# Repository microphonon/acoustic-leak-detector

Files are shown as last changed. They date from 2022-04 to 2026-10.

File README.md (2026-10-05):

# acoustic-leak-detector
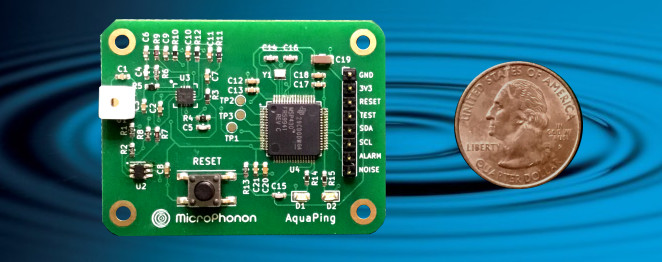
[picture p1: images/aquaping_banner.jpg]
MicroPhonon Acoustic Leak Detector


The best place to start is with the comprehensive user guide. An academic paper that describes the device design and performance can be found at [arXiv.org](https://arxiv.org/abs/2511.00348). 

 The AquaPing hardware with pre-loaded firmware is available for purchase at [Mouser](https://www.mouser.com/ProductDetail/MicroPhonon/CS-AQUAPING-01?qs=IPgv5n7u5QZ96LnbcZcGBA%3D%3D) or  [Crowd Supply](https://www.crowdsupply.com/microphonon/aquaping).

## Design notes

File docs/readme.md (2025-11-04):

# Documentation

In this repository:
- Acoustic leak detector design guide and I2C communication instructions (.pdf)
- Top-level firmware flow chart (.jpg)
- One-page engineering brochure (.pdf)
- Detecting simulated leaks inside a drywall structure (.pdf)

An academic paper describing the engineering design of the acoustic leak sensor is available for free download at [arXiv.org](https://arxiv.org/abs/2511.00348).

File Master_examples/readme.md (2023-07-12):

# Master firmware examples

Sample code to periodically read/write bytes from/to the AquaPing slave on the I2C bus. 
    Developed and tested with a Lolin D1 mini WiFi module as master, but should adapt to 
    other devices using the Arduino IDE and equivalent libraries. The D1 mini uses the Espressif ESP8266 for WiFi capability.
    
- **D1_mini.ino**  D1 mini transfers data between PC and sensor
-  **ThingSpeak.ino** D1 mini is used to: i) transfer data between PC and sensor and ii) upload data to ThingSpeak server over WiFi
    
 The D1 mini module provides a UART to USB interface to allow communication with a PC. 
    Any serial terminal program (eg. putty) should work; be sure to set equivalent baud rates. 
    The master can monitor the alarm state of the slave with a separate INTERRUPT_PIN (lowest latency) 
    as well as reading the first byte of the status_array. 
    
 Command characters are read from the serial terminal as user input. Characters are echoed to 
    the terminal then formatted into command strings as a sequence of hex bytes that are sent to slave. 
    Syntax is in separate documentation.

 The sensor status is polled at a period set by polling_interval in milliseconds. The retrieved 
    status bytes are then sent to the terminal. Each I2C read operation is signaled by the D1 mini LED blinking. 
    To allow the user to send sensor configuration commands with reasonably low latency, the terminal 
    is checked for input with a period set by sleep_delay. 
    
It is important to understand that the rate at which
    the master polls the slave (i.e. sensor) is not the same rate that the sensor polls the environment. These polling 
    loops run asynchronously. The slave MCU prevents I2C bus conflicts by moving data via Direct Memory Access, which requires no
    CPU intervention. 

The D1 mini can supply 3V3 external power to the sensor.
    Make sure a large electrolytic filter capacitor is on this line.
    The module already has pullup resistors for SDA and SCL.

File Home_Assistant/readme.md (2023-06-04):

# AquaPing demo with Home Assistant

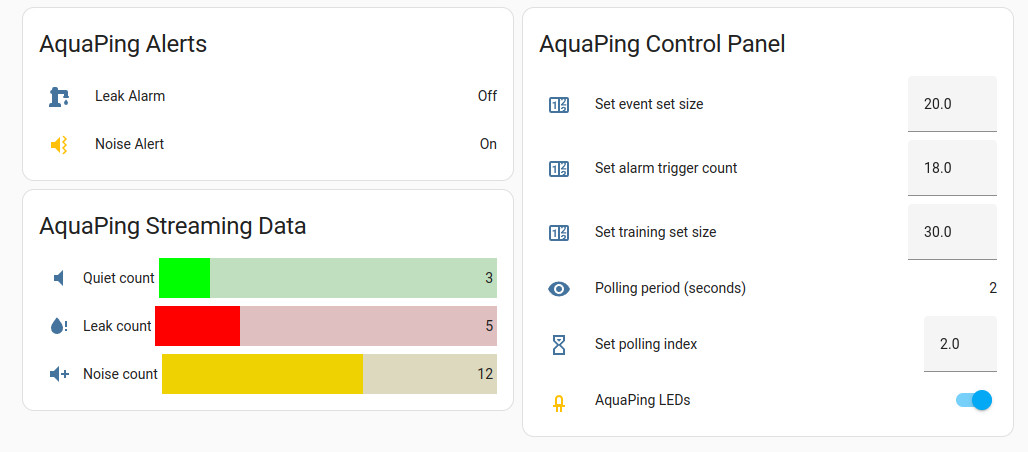
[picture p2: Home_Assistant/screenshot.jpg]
AquaPing Home Assistant Demo


This repository demonstrates how the [AquaPing](https://www.crowdsupply.com/microphonon/aquaping) acoustic leak detector can be interfaced to Home Assistant with [ESPHome](https://esphome.io/). It uses the ESP8266 WiFi module on an inexpensive [D1-mini](https://www.wemos.cc/en/latest/d1/d1_mini.html) breakout board. Although WiFi is not the preferred wireless protocol for ultralow power IoT applications, this Home Assistant application is useful for illustrating the sensor's principles of operation and its capabilities. Real-time data is displayed on a custom HA UI frontend that is also used to configure the sensor monitoring parameters.

The AquaPing is designed to listen for very weak, high frequency acoustics that may accompany a pressurized plumbing leak. The frontend screenshot shown above depicts sensor operation with music playing nearby. This is impairing the sensor's ability hear potential leak signals. An appreciable number of sample counts are being interpreted as noise causing the corresponding alert to trigger (On). Noise discrimination and rejection are important for preventing false leak alarms.

Development was done running the Home Assistant operating system inside VirtualBox on Ubuntu Linux. [ESPHome](https://esphome.io/) is installed as a native Home Assistant Add-on. The *aquaping.h* header file must be present in the config/esphome/ directory. It can be configured with the HA File Editor Add-on and is an *include* in the custom ESPHome yaml file that is found in this repository. The optional horizontal bar graphs require the [bar-card](https://github.com/custom-cards/bar-card) and [config-template-card](https://github.com/iantrich/config-template-card) modules that were installed using [Home Assistant Community Store](https://hacs.xyz/) (a github account is required). There are plenty of good online tutorials that can guide you through the various install processes.

## D1-mini hardware

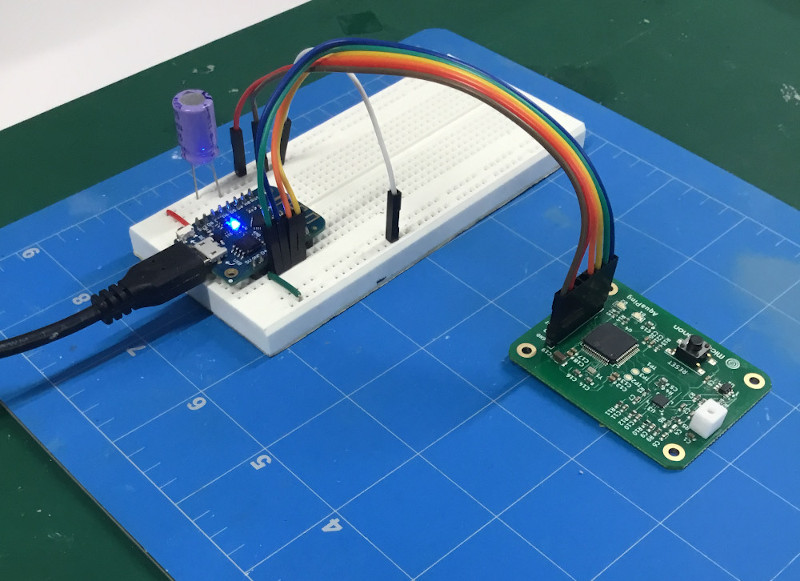
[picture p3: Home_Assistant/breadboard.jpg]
D1-mini hardware


The D1-mini is an inexpensive ESP8266 WiFi breakout board that is available from a variety of vendors. It communicates with the AquaPing using the I2C interface. SCL connects to pin D1 and SDA to pin D2 on the D1-mini. Pullup resistors are already present on the breakout board. The D1-mini can supply 3V3 DC power to the AquaPing *provided* the supply rail is sufficiently quiet. In the photo above, a 220 uF electrolytic decoupling capacitor is placed across 3V3 and ground on the breadboard. The NOISE and ALARM pins of the AquaPing are connected to D3 and D4, respectively. These lines provide an immediate GPIO interrupt if a suspected leak or persistent noise are detected. Other GPIO pins may be used if the configuration is appropriately modified.

Because the D1-mini operates as an always-on WiFi radio, its power consumption will be orders of magnitude greater than the AquaPing sensor. In this demo, power is supplied through the USB connection on the breakout board. If the USB connection is made to a host computer, a serial terminal program (eg. puTTY) can also be used to communicate with the AquaPing. Default baud rate is 9600; adjust as needed in the *aquaping.h* file. More information about the serial protocol can be found in the AquaPing user guide located in this repository.

Another option that could allow extended battery operation is to place the D1-mini in deep sleep, wake it up at periodic intervals, and let it re-connect to the WiFi router. The longer the period, the greater the battery life, but with increased sensor latency. This would require modifications to the D1-mini firmware.

## D1-mini firmware

C++ code to control operation of the D1-mini is in the header file *aquaping.h*. It uses the common Arduino abstractions and must be declared as an include in the yaml file. It is important to understand that this demo implements two independent, asynchronous polling loops running on the D1-mini and AquaPing:

1) **Polling the sensor.** Sensor information is downloaded to and uploaded from Home Assistant over WiFi with a period set by the 'update_interval' (ms) in the D1-mini firmware; default is 10000 ms, i.e. 10 seconds. 

2) **Periodic analysis of the environmental acoustics.** The AquaPing spends most of the time in a sleep state, but periodically wakes up to sample the acoustic environment. This interval is set by selecting one of 9 fixed periods with duration in the range 1--30 seconds; see the user manual. 

There are many examples of sensors uploading data via I2C and displaying it on the Home Assistant dashboard. Going in the other direction, however, is not well documented. This capability is needed to send configuration parameters to the AquaPing.  In this demo, frontend data is passed through the ESPHome yaml to the firmware where it is sent as byte pairs using the *Wire* library. The methodology used for I2C read/write operations is illustrated in [this document](i2c.md).

### Troubleshooting
When firmware is already loaded on the D1-mini, ESPHome may not be able to overwrite it. If the reset button is ineffective, try the following procedure: On the D1-mini, connect pin D3 to ground, pin D4 to 3.3V, and pin D8 to ground. Then try flashing the new firmware from ESPHome.

## Dashboard

The Home Assistant dashboard is highly configurable. Three dashboard cards are used here for alerts, streaming data, and control. Interrupts for potential leaks and anomalous noise are immediate and displayed on the alert card. The dashboard card with the data counts is updated only on each WiFi polling cycle, which introduces some latency. Similarly, adjustments to the AquaPing control panel are transmitted to the sensor at the same rate and latency. 

The alarm_trigger_count must be set to less than or equal to the event_set_size. If set higher, it will be coerced to the event_set_size. The control panel selects the polling period with an integer index (1--9) and the corresponding time is displayed in seconds. If the training_set_size is changed, a new training session will be automatically initiated. All configuration parameters are explained in the user guide. A switch is provided to enable/disable the AquaPing LEDs.

The horizontal bar graphs are optional, quite tricky to setup, and require installation of the [bar-card](https://github.com/custom-cards/bar-card) and [config-template-card](https://github.com/iantrich/config-template-card) modules. The latter is needed to re-scale the graph maxima when the user changes the event_set_size. See the included dashboard file for the syntax. There may be alternative techniques that could work better to render these graphics. Real-time counts can also be displayed using simpler numeric indicators. These can be added to the dashboard by editing the ESPHome yaml file.

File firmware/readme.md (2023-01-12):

# Modifying and compiling the code
The firmware was developed using Code Composer Studio 9.3.0 on an Ubuntu-Linux platform. CCS is a free download from Texas Instruments and provides an Eclipse style interface. The MSP430FR5994 MCU on the PCB is flashed using the Spy-Bi-Wire two-terminal interface marked RESET and TEST on the leak sensor PCB. Almost any variety of inexpensive TI Launchpads can be used for this purpose. The Launchpads have a debugger and an Energy Trace function that is useful for identifying code inefficiencies and estimating battery life. Alternatively, compiled binaries can be flashed with the MSP430-BSL made by Olimex and available at [Mouser](https://www.mouser.com/ProductDetail/Olimex-Ltd/MSP430-BSL?qs=J7x7253A5u5ktaUHQ83VeQ%3D%3D).

A capability for over-the-air firmware updates is an anticipated future upgrade. This can be accomplished using the I2C terminals SDA and SCL in addition to the RESET and TEST pins. The required MCU part number is MSP430FR59941 as distinguished from MSP430FR5994 that uses a UART connection with the master. A UART design must include TXD and RXD pins, increasing the header pin count from 7 to 9. If OTA upgrades are not necessary, either variety of MCU will work.

The Texas Instruments [MSP DSP Library](https://software-dl.ti.com/msp430/msp430_public_sw/mcu/msp430/DSPLib/1_30_00_02/exports/html/index.html) must be installed on the development platform, also a free download.  Use your file explorer to copy the dsplib directory directly into the CCS project folder. Enable DSP by navigating to:

 CCS Build: MSP430 Compiler: Include Options

and adding the following line:

 ${PROJECT_ROOT}/dsplib/include
 
The 48-pin version was used for the prototypes and is archived here. For the production run in late 2022, only the 64-pin MSP430FR59941 MCU was available; ongoing firmware development and updates are being done for this hardware. As of December 2022, the 64-pin sensor is being sold by Crowd Supply and Mouser. The firmware version can be read from the status array (see user manual).

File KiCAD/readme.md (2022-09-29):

# KiCAD files
There are two versions of the PCB for designs using either a 48- or 64-pin MSP430FR5994 microcontroller. Both the schematic and layout KiCAD files use some custom components. These are probably already available online somewhere, but I decided to make my own 
footprints following the manufacturer data sheets to reduce the risk of fabrication problems.

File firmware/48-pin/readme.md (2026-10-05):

Firmware version 52: This adapts version 51 firmware for the 64-pin MCU to work with the pre-production sensor hardware with a 48-pin MSP430FR5994. This board has a 7-pin header and does not have the NOISE alert pin. Otherwise, performance is identical.

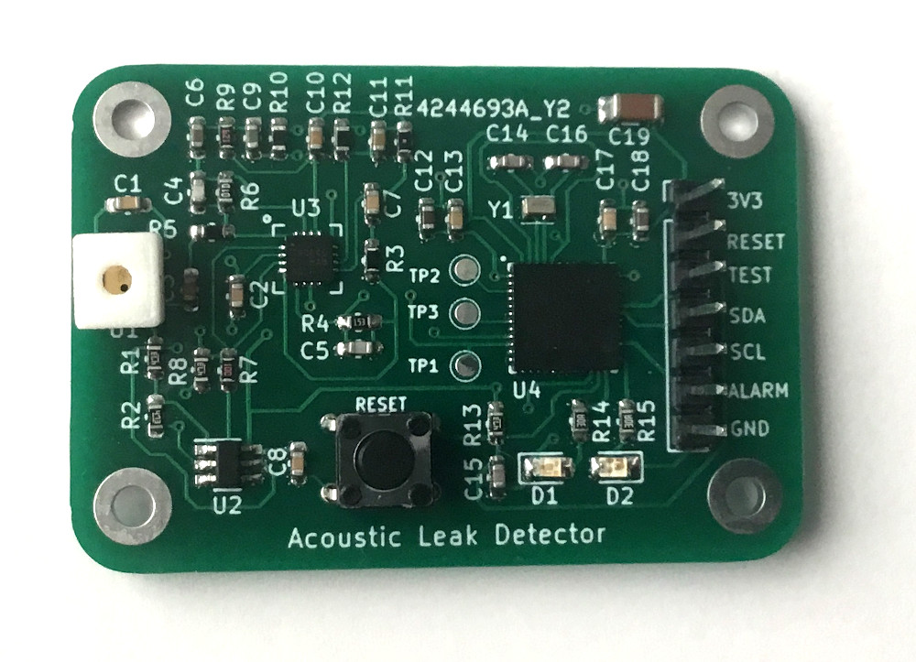
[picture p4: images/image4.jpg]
MicroPhonon Acoustic Leak Detector


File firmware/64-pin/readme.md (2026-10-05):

Firmware version 51: Update after a firmware review by claude.ai. The AI suggested increasing the memory allocated to some of the integer variables that are generated via arithmetic multiplication. This will reduce the risk of overflow and may increase the sensor dynamic range. Also fixed a small bug that writes Byte 10 of the Status_Array.

Firmware version 50: Syntiant acquired the Knowles product line of SiSonic MEMS microphones. In their new data sheet, Syntiant recommends a 40 ms delay after the application of bias voltage to allow the microphone to attain full sensitivity. The Aquaping uses pulse bias on every acoustic acquisition to maximize battery life. To incorporate this new specification, the firmware has been revised to increase IWAIT from 5 ms to 40 ms. The interval between rapid multiple acquisitions (NWAIT) has been decreased to compensate.

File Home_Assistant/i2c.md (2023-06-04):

# Custom I²C Component on ESPHome

The wiki at ESPHome provides very little information on how to communicate with a custom slave device (eg. a newly developed sensor) from the dashboard using I²C. An approach for doing this is described here. The [Custom Sensor Component](https://esphome.io/components/sensor/custom.html) documentation describes how to setup and register a custom sensor. A custom component class is defined in a header file using Arduino-style code that is tagged as an include in the yaml file. Consult the above link for details and some example code.

## Dashboard Interfacing: I²C Write

It may be useful to write to a slave register via I²C using a numerical input from the dashboard. For example, the following yaml code snippet captures a user-supplied numerical input in the range 1--255:

```
    number:
        - platform: template
        name: "Input 1"
        optimistic: true
        min_value: 1
        max_value: 255
        initial_value: 20
        step: 1
        mode: box
        id: input_1
```
        
We want to write this number to a ``REGISTER_ADDRESS`` on the slave device using a timed polling loop:
 
```
    #include "esphome.h"
 
    const uint16_t I2C_ADDRESS = 0x21;
    const uint16_t REGISTER_ADDRESS = 0x78; 
    const uint16_t POLLING_PERIOD = 15000; //milliseconds
    char temp = 20; //Initial value of the register

    class MyCustomComponent : public PollingComponent {
     public:
      MyCustomComponent() : PollingComponent(POLLING_PERIOD) {}
      float get_setup_priority() const override { return esphome::setup_priority::BUS; } //Access I2C bus

      void setup() override {
        //Add code here as needed
        Wire.begin();
        }
  
      void update() override {  
      char register_value = id(input_1).state; //Read the number set on the dashboard
      //Did the user change the input?
      if(register_value != temp){
            Wire.beginTransmission(I2C_ADDRESS);
            Wire.write(REGISTER_ADDRESS);
            Wire.write(register_value);
            Wire.endTransmission();
            temp = register_value; //Swap in the new value
            }
          }
    };
```

The ESP device (master) checks the dashboard with a period defined by ``POLLING_PERIOD``; in this example every 15 seconds. The numerical value from the dashboard is accessed with its ``id`` tag and its state is set to the byte variable that we call ``register_value``.  To prevent an I²C write on every iteration, the contents of the register are stored in ``temp`` and checked for any change. 

## Dashboard Interfacing: I²C Read

To read and display data from a sensor that is slave on the I²C bus, it is instantiated as explained in Step 2 on the [Custom Sensor Component](https://esphome.io/components/sensor/custom.html) page. In the  yaml file below, three register values on the slave are made available to the dashboard:

```
    sensor:
    - platform: custom
    lambda: |-
        auto my_sensor = new MyCustomComponent();
        App.register_component(my_sensor);
        return {my_sensor->register_value_1,my_sensor->register_value_2,my_sensor->register_value_3};

    sensors:
    - name: "Data 1 Display" 
    - name: "Data 2 Display"
    - name: "Data 3 Display"
  ```

The timed polling loop is modified to periodically retrieve three sequential data bytes beginning at ``REGISTER_ADDRESS``. Three pointers are defined to publish the data bytes:

```
    #include "esphome.h"

    const uint16_t I2C_ADDRESS = 0x21;
    const uint16_t REGISTER_ADDRESS = 0x78;
    const uint16_t POLLING_PERIOD = 15000; //milliseconds
    static char Data_array[3];

    class MyCustomComponent : public PollingComponent {
        public:
        Sensor *register_value_1 = new Sensor();
        Sensor *register_value_2 = new Sensor();
        Sensor *register_value_3 = new Sensor();
    MyCustomComponent() : PollingComponent(update_interval) {}  
    float get_setup_priority() const override { return esphome::setup_priority::BUS; } //Access I2C bus

    void setup() override {
    //Add code here as needed
    Wire.begin();
    }

    void update() override { 
    // Read 3 bytes in sequence starting at REGISTER_ADDRESS
        Wire.beginTransmission(I2C_ADDRESS);
        Wire.write(REGISTER_ADDRESS);
        Wire.endTransmission(); // End write; starting register address is now specified
        Wire.requestFrom(I2C_ADDRESS, 3); 
        //Could also do this in a loop
        Data_array[0]=Wire.read(); 
        Data_array[1]=Wire.read(); 
        Data_array[2]=Wire.read();       
        //Publish the sensor data on the Home Assistant GUI
        register_value_1->publish_state(Data_array[0]);
        register_value_2->publish_state(Data_array[1]);
        register_value_3->publish_state(Data_array[2]);
        }
      };
 ```

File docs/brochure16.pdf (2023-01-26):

# Battery-Powered Acoustic Leak Detection

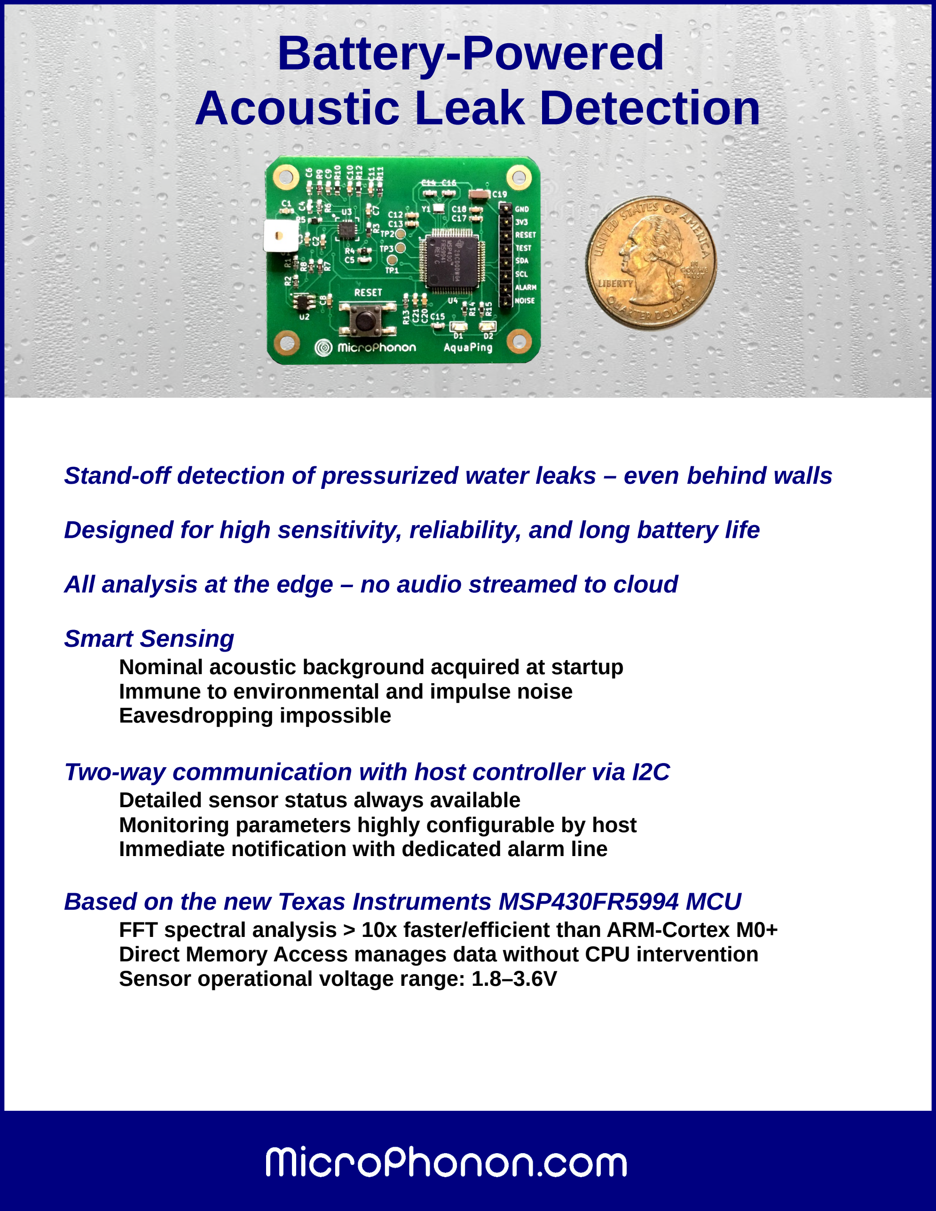
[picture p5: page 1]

Stand-off detection of pressurized water leaks – even behind walls

Designed for high sensitivity, reliability, and long battery life

All analysis at the edge – no audio streamed to cloud

Smart Sensing
Nominal acoustic background acquired at startup Immune to environmental and impulse noise Eavesdropping impossible

Two-way communication with host controller via I2C
Detailed sensor status always available
Monitoring parameters highly configurable by host
Immediate notification with dedicated alarm line

Based on the new Texas Instruments MSP430FR5994 MCU
FFT spectral analysis > 10x faster/efficient than ARM-Cortex M0+ Direct Memory Access manages data without CPU intervention Sensor operational voltage range: 1.8–3.6V

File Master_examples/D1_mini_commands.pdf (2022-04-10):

Configuring the AquaPing sensor using a D1 mini and serial terminal program

M.P. Hasselbeck MicroPhonon April 2022

A UART serial terminal program like putty or minicom can be used to monitor sensor operation and send it a variety of commands. The following eight commands are converted to suitable byte strings by the D1 mini (ESP8266) that are passed to the sensor via I2C. The structure of all commands except reset (single character r) is a single lower-case alphabetic, followed by a 1–3 digit numeric, and the Enter key. As an example, the polling period is set to 10 seconds by entering the command: o5

Multiple commands can be sent provided there is a single space between them. Commands can be sent in any order as long as the proper syntax is used. Example: The data collection set is resized to 128 and LEDs are turned off by entering: e128 l0

The commands shown in Table I create persistent settings that remain in the sensor’s non-volatile memory after power cycling:

Parameter | Lower case character | Numeric arguments | Corresponding values
LEDs | l | 0 or 1 | On or Off
Background | b | 10–255 | 10–255
Polling period | o | 1–9 | 1, 2, 3, 5, 10, 15, 20, 25, 30 sec
Event array size | e | 10--255 | 10–255
Trigger count | t | 10–255 | 10--255

Table I. Persistent sensor parameters

The commands shown in Table II control the sensor from the terminal. The sensor is always in an active state after power cycling.

Control | Lower case character | Arguments | Action
Power state | p | 0 or 1 | Sleep or Active
Alarm | a | 0 or 1 | Enable or Disable
Reset | r | | Set all parameters to defaults

Table II. Non-persistent sensor controls

All of the above commands will erase any accumulated data and counting will begin fresh. The sensor will reject a setting with Trigger count > Event array size. D1 mini defaults: 9600 baud/sec; 10 sec polling. Modify the firmware as needed. Interface to host computer with USB-micro cable.

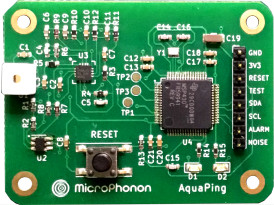
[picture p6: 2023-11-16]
images/aquaping8.jpg

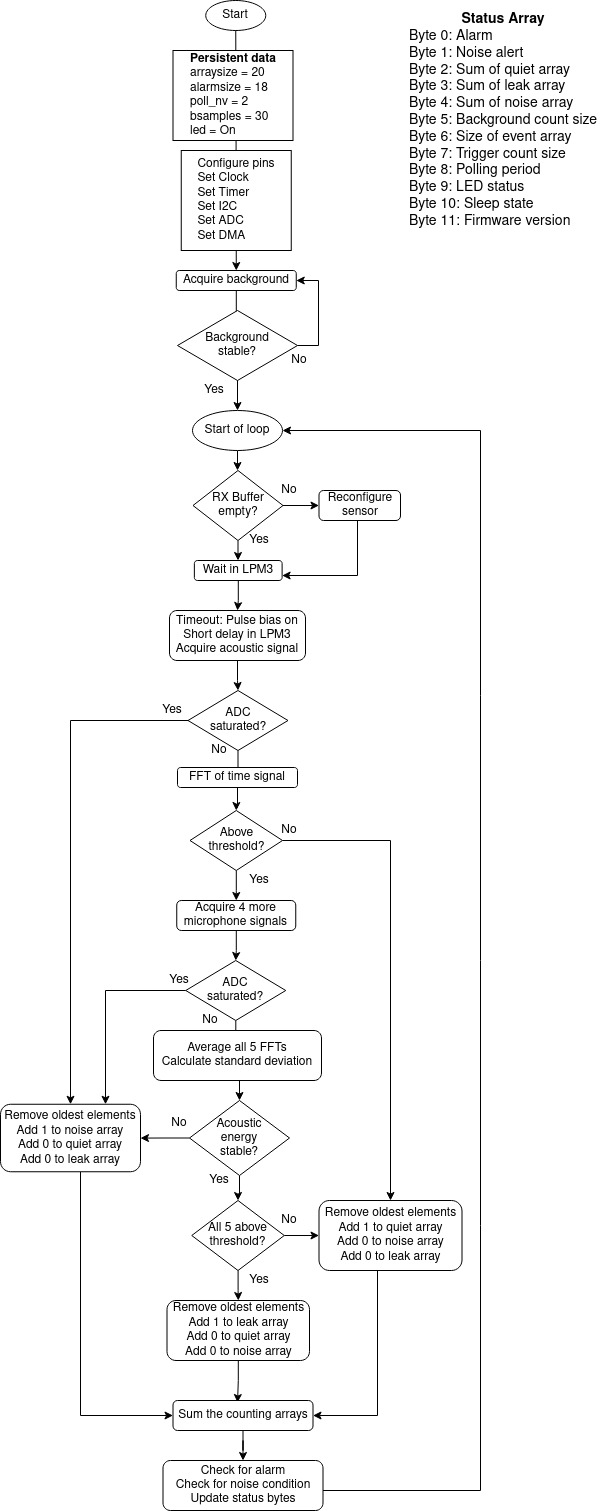
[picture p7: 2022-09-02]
docs/flow_chart_FFT.jpg

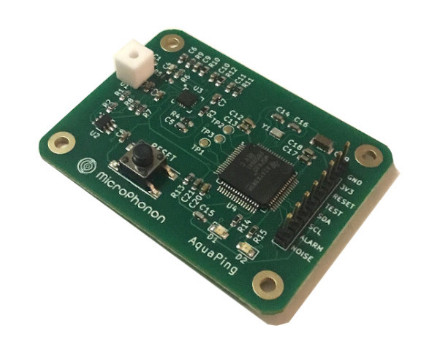
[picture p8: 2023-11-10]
images/aquaping5.jpg

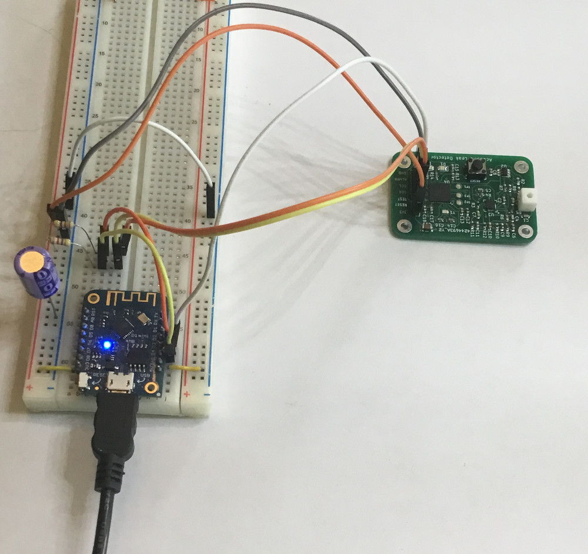
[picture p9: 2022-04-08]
images/D1mini.jpg

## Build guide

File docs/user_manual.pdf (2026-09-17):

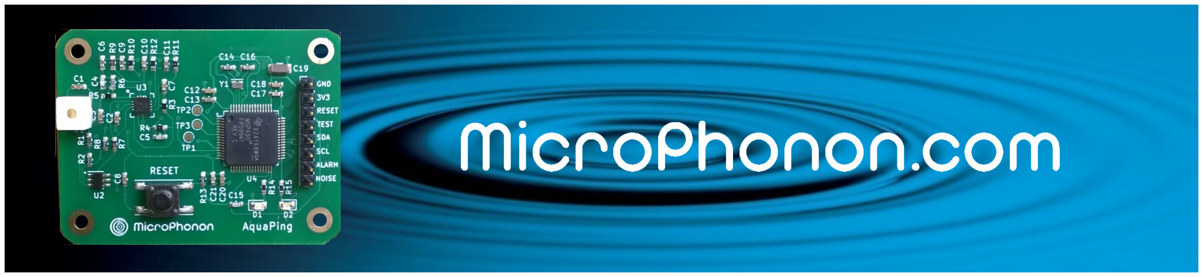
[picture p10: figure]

AquaPing Acoustic Leak Detector User Manual Version 0.21 © 2026 MicroPhonon LLC

## I. Electrical Specifications

| Minimum | Maximum | Units
Supply Voltage | 1.8 | 3.6 | VDC
Active current 1 | 3.2 | | mA
Sleep current 1 | | 4 | μA
ALARM pin output current | | 6 | mA
NOISE pin output current | | 6 | mA
[1] LEDs off and alert pins not connected

## II. Principle of Operation

When pressurized water escapes from a seam, crack, or loose fitting on plumbing, broadband high frequency acoustics are emitted. These signals can travel an extended distance (> 30 feet) in free-space and be detected by a remote sensor. This suggests a stand-off method for water leak detection that is substantially different compared to conventional contact moisture sensors and various types of smart flow meters installed on or inside of plumbing lines.

The AquaPing combines the principles of glass breakage and smoke detectors. Glass breakage occurs on a timescale of a few seconds or less, requiring continuous data acquisition at rates approaching 1 kHz or more. Almost all plumbing leaks are persistent, which allows for sub-Hz sampling rates and exceptional battery life. In a typical application, two AAA alkaline batteries should power the AquaPing for multiple years.

Glass breakage has the advantage of being generally louder than the ambient environment so that detector sensitivity is not an issue. Small water leaks, especially when when separated from the sensor by acoustic barriers such as walls, are likely to be at or below the environmental background. Much higher sensitivity and noise mitigation are essential. This can be addressed by active (analog and digital) and passive (mechanical) filtering along with judicious use of statistical analysis.

The acoustic approach to water leak detection presented here works well but is not capable of identifying all water issues. It will not respond to leaking roofs or melting ice, for example. The nature of the pressurized orifice is also important. A smooth hole drilled into a pipe will produce a Laminar flow jet that emits a much weaker acoustic signal – perhaps undetectable – compared to a jagged crack or loose fitting at the same backing pressure. Acoustic sensing can be used to complement standard leak detection techniques and will be especially useful when monitoring large areas.

The AquaPing is intended to be deployed as a remote, wireless network node. There are many dozens of wireless protocols, however, so it was decided to make the device agnostic to the host hardware and thus have the widest possible use cases. It will work with any controller having an I2C interface and 3V3 power bus.

The sensor has been designed to work in an environment with a stable, relatively quiet acoustic background. Human activity will often produce noise that will impair the sensor’s ability to hear leaks. The formation of puddles and similar indicators of water escaping, however, are usually obvious and quickly noticed. Best performance and reliability are attained in conditions where people are not present.

## III. Configuration

Acoustic environments vary considerably and the sensor must be configured by the host controller for different and possibly changing conditions. Two key considerations are: i) duration of the training time and ii) duration of data acquisition. Configuration parameters are set by the host on the I2C bus; see Section V.

1. Training time Training happens entirely on the AquaPing; no audio is sent to the cloud. Sensitivity is set automatically during startup and requires the device to acquire a set of background samples. Data is gathered at a 1 Hz rate with sample size that is user-configurable in the range 10–255; default is 30 seconds. The environment should be nominally quiet and leak-free. If statistical analysis of this data determines that the background acoustic level is sufficiently stable, the green LED blinks once and the firmware transitions to monitor mode. If not, the red LED blinks twice and the background acquisition repeats until stability is attained. If the sensor cannot find a sufficiently stable background, it will loop indefinitely in the training mode. If the red LED blinks three times during training, the power source is too noisy. The counting arrays (Section IV.3) will remain at zero when either of the above conditions keep the sensor stuck in training mode. Refer to Section VII (Troubleshooting).
2. Time sampling window When the sensor is monitoring, it acquires a constantly updated time-series data set. The product of event array size times the polling period determines the time sampling window. This is set by the user and requires some situational awareness. To illustrate, consider an example application that places the AquaPing in a bathroom with a shower. The sound from a normally running shower might be interpreted as a leak signal. To prevent false alarms, the sampling window can be set for 20 minutes; persistent signals exceeding this time would alert for a potential leak. An array size of 120 and polling period of 10 seconds will produce the desired 20 minute window (1200 seconds). To allow for acoustic irregularities, the alarm trigger count can be set lower than the event array size, eg.
100. The alarm trigger count is not critical and is a free parameter for testing and experimentation.

It may be advantageous for the controller to put the sensor to sleep when its operating environment is known to be noisy. This will save battery power and prevent false alarms. The sensor also has an automated noise mitigation capability that helps prevent false alarms; see Section IV.4.

3. Quick start: Out of the box operation The default settings can be used to demonstrate the AquaPing without need for a controller on the I2C bus. Simply connect a quiet DC power source at the positive 3V3 and GND pins. Double-check the connections as there is no reverse polarity protection. At startup or reset, the green-red LEDs will blink in sequence. The sensor will first acquire a 30 second background and – if the background is determined to be sufficiently stable – begin polling with a 2 second period as described above. The green and red LEDs will blink in response to the acoustic environment; details of LED signaling are in Section IV.4.

## IV. Design

The sensor is fabricated on a 53 x 40 mm²
PCB using standard, low cost electronic components. It is designed to work with a host controller as part of a low power wireless system with a well-filtered 1.8– 3.6 VDC power source. Two-way communication takes places via I2C. All sensor training, signal processing, and analysis occurs on the device; no audio is ever sent to the cloud. Real-time sensor information is available on-demand as 12 status bytes.
1. Analog front-end The acoustic transducer is a surface-mount Knowles SiSonic MEMS microphone that forms one end of a rectangular Helmholtz resonator. The resonator center frequency is ~ 9 kHz with Q ~ 30. The microphone signal is amplified 40 dB and sent to a 2-stage, 4th-order Sallen-Key high-pass filter with 3 dB cutoff at ~ 8 kHz. This is followed by a 23 dB post-filter gain stage. The microphone is pulse-biased and the amplifier stages are gated on-off to increase battery life. To illustrate, if a single audio acquisition occurs every 2 seconds (default), the sensor will be in sleep mode > 99% of the time. The user-selectable polling period is sourced to a low-power clock that is referenced to a board-mounted 32768 Hz crystal. Total current draw in sleep mode is < 4 μA corresponding to ~12 μW of continuous power consumption. Each acoustic sampling event uses ~140 μJ with a momentary peak current of about 3.2 mA.

The microphone and resonator provide some sound collection directivity and the PCB can be oriented for this purpose. Be aware that acoustics can bounce off surfaces like walls and ceilings (reverberation), which can complicate locating the signal source.

2. Signal processing After the filtered signal leaves the analog front-end, a 12-bit ADC in the MCU collects 256 sample points at 33.3 kS/s corresponding to a 7.68 ms duration temporal acquisition. The data is checked for ADC saturation and tagged as noisy if necessary. If no saturation has occurred, the MCU performs an FFT of the time data using a uniform window, as appropriate for broadband white noise. The LEA of the Texas Instruments MSP430FR5994 calculates the FFT > 10x faster and more efficiently than an ARM-Cortex M0+. The spectral data is rendered as an array of complex numbers separated by 130.2 Hz frequency steps. A 34 point subset in the range 7–11.5 kHz is selected. The spectral energy at each frequency step is calculated and then summed to provide the total acoustic energy in the frequency window. The combination of mechanical, analog, and digital filtering greatly reduces the influence of background noise, dramatically reduces the potential of ADC overload, and eliminates the possibility of intelligible conversations being discerned if the sensor network becomes compromised, i.e. eavesdropping is impossible.
3. Analysis Each polling cycle analyzes the acoustic signal and designates it as one of the following three events: quiet, leak, or noise. These events are accumulated in three separate data arrays. The value 1 is entered if that specific event occurs; otherwise it is counted as 0. For example: if a leak signal is detected, a 1 is added to the leak array while 0 is placed in the quiet and noise arrays. As new events are added, the oldest events are removed, i.e. the fixed-size data arrays slide in time.
All data arrays are the same size and contain elements that are either 0 or 1. The array size is configured by the host in the range 10–255; default is 20. Size and polling rate determine the time over which a full data set is acquired. The default 0.5 Hz polling rate and 20 event set size define a 40 second data accumulation window. This time sampling window will depend on the application and should be adjusted by the user as necessary. If the environment is known to always be nominally quiet, a short time window will identify a potential leak quickly. In a bathroom where a shower may be running 20 minutes or more, the time sampling window must be longer than this to avoid false alarms.

If leak events become an appreciable portion of the time sampling window, an alarm condition may exist. Ideally, all events in the window will be identified as leaks. In practice, environmental noise, irregularities in water flow, pressure fluctuations, the presence of bubbles, or other acoustic disturbances may be recorded as quiet or noise events – not leaks. To account for non-ideal signals, the alarm trigger size can be independently set below the event set size. The trigger value is not critical; testing has shown that 80–90 percent of the event set size is a good choice. The default values are 18 for the trigger size and 20 for the event size.

When a potential leak is identified, the sensor provides an immediate alert by switching the digital ALARM line to the high state (logic 1). The host controller can monitor this line with an interrupt. The corresponding status byte is also set; see I2C communications in Section V.

The real-time count of quiet, leak, and noise events are available at any time by querying the sensor via I2C. If noise events become significant, the noise status byte is set. This is important, as leak detection is compromised when ongoing noise is present. The count of quiet, leak, and noise events sum to the event set size.

4. Noise mitigation To hear the smallest leaks, the electronics must be configured to have high sensitivity to very weak signals. The trade-off is increased susceptibility to ambient environmental noise that can increase the probability of false alarms. The sensor is adept at identifying and ignoring various types of noise. Excessive noise will, however, mask the presence of a leak. By accumulating statistics from each polling cycle, the sensor can inform the host controller that it is operating in a noisy environment.

On power-up or after a reset, the green-red LEDs will blink in sequence; the sensor then enters a training session to learn about the ambient acoustic environment. It collects a set of acoustic signals of duration ~ 8 ms at a 1 Hz rate. The size of the background data set can be in the range 10--255; default is 30 corresponding to a 30 second total acquisition time. The data is analyzed by the AquaPing to get an average background (xB) and standard deviation (sB). If 2sB > xB, the background is determined to be too noisy for reliable operation. The red LED blinks twice and a new background data set is collected. To obtain additional noise rejection, the acoustic data stream is checked for ADC overload. Excessively loud signals are discarded and the individual acquisition is repeated. This continues until the background acoustic environment is sufficiently quiet and stable. The green LED blinks once and the sensor transitions to monitoring.

The ambient acoustic level and electronic noise floor determine the sensitivity to leaks. For this reason, a well filtered supply voltage must be placed on the 3V3 terminal. Battery power does not guarantee immunity from noise originating in other electronics that can propagate into the sensor board, potentially causing oscillation of the high-gain amplifier stages. This is signaled by three blinks of the red LED during training; refer to Section VII for advice on troubleshooting this problem.

Once the background is established, the sensor begins polling at a user defined rate; default is 0.5 Hz. Slower polling rates increase battery life. The ADC audio samples are first checked for saturation. If an excessively loud signal is present, a noise event is recorded, the red LED blinks twice, and the firmware enters a sleep state to wait for the next polling cycle.

The training session sets the sensitivity level for detecting a leak signal, which is one standard deviation above the noise floor: xB + sB. If there is no ADC overload, the spectral energy (x0) derived from an FFT of the temporal data is checked. If x0 < xB + sB, no leak is detected and a quiet event is recorded; the green LED blinks once. If x0 > xB + sB, additional processing commences: four sequential acoustic measurements are made; these are separated by 50 ms corresponding to a sampling rate of about 20 Hz. If any of these additional acquisitions saturate the ADC, further processing aborts, an environmental noise event is recorded, the red LED blinks twice, and the polling loop pauses for the next iteration.

If all five filtered audio signals are within the dynamic range of the ADC, their individual spectral energies (xi : i=0–4) are used to calculate the average energy (x) and standard deviation (s). If 2s > x, excessive fluctuations are present in the data set. This indicates a level of environmental noise that prevents reliable leak detection. This polling cycle is recorded as a noise event, the red LED blinks twice, and the program waits in low-power mode for the next timed iteration.

If the acoustic energy fluctuations are sufficiently small, the next step is to check if all five spectral energies (xi ) exceed the leak signal threshold: xi > xB + sB. When this occurs, a leak event is recorded and the red LED blinks once. Otherwise, this loop iteration is associated with impulse noise, but recorded as a quiet event. The green LED blinks twice.

LED signaling is summarized in the following chart:

DURING SENSOR TRAINING

Green-red LEDs flash in sequence | Training session has started
Green LED flashes once | Training completed successfully. Transition to monitoring
Red LED flashes twice | Training session was unsuccessful. Automatically repeats
Red LED flashes 3 times | Input ADC overload occurred. This training data rejected

DURING SENSOR MONITORING

Green LED flashes once | Nominally quiet
Green LED flashes twice | Short-duration impulse noise detected. Recorded as quiet
Red LED flashes once | Potential leak signal detected
Red LED flashes twice | Noise detected

Performing the sequence of tests and checks described in this section ensures that only persistent, stable signals in the target acoustic frequency range are counted as leak events. This is a design trade-off between sensitivity and reliability that is needed to reduce false alarms. A system flowchart is available on the project github. (https://github.com/microphonon/acoustic-leak-detector/tree/main/docs)

## 5. Interfacing

An 8-pin header (2.54 mm spacing) provides the following connections:

3V3, GND | Connect a power source to these pins in the range 1.8–3.6 VDC. The supply should be as quiet as possible, so add filtering as necessary. There is no reverse polarity protection.
SDA, SCL | I2C data and clock lines, respectively. External pullup resistors required.
ALARM | Digital line switches from low to high when a leak has been detected. Controller can monitor this line with an interrupt.
NOISE | Digital line switches from low to high when persistent noise has been detected. Controller can monitor this line with an interrupt.
RESET, TEST | Firmware is uploaded using these pins. Program the MCU with a Texas Instruments MSP430 Launchpad and the Spy-bi-Wire protocol. Momentarily pulling RESET low is equivalent to the button press.

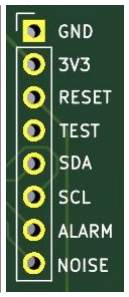
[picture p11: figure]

Reset Button. Pressing this button causes the green-red LEDs to blink in sequence; a new ambient background is acquired. This button also provides an escape in the unlikely event of a firmware freeze. Does not do a full system reset as the persistent settings in Table I in Section V are retained.

Test Point 1 (TP1). Output of the analog filter and input to the ADC.
Test Point 2 (TP2). Monitors timer TA1 in the ADC.
Test Point 3 (TP3). Digital line that toggles at the completion of each ADC conversion. Disabled by default; enable by editing the firmware in function CheckMic().

## V. I2C write and read operations

This section describes how a master controller interfaces with the slave sensor on the I2C bus. Recommended clock rate: 100 kHz. External pullup resistors required (4.7k recommended). The default I2C address 0x77.

1. Commands (write only) All commands are sent as two-byte pairs. Send START, followed by the 7-bit slave address and the R/W bit cleared, then the desired command hex code and a single byte data field as shown in Table 1. Finally, assert NACK and STOP. Between 1 and 8 pairs (hex code byte + data byte) can be sent, provided there are an even number of bytes. The hex code and/or data byte can be sent as hexadecimal or decimal. With one exception, all write commands clear the counting arrays. Either a two-byte sequence to turn the LEDs on (0x6C 0x31) or off (0x6C 0x30) will not clear the counts.
COMMAND | HEX CODE | DATA BYTE
System reset | 0x72 | 0x72
Alarm | 0x61 | 0x30 or 0x31 (Off or On) Default Off
Sleep | 0x70 | 0x30 or 0x31 (Sleep or Active) Default Active
Background array size* | 0x62 | 0x0A – 0xFF (10 – 255) Default: 30
Event array size* | 0x65 | 0x0A – 0xFF (10 – 255) Default: 20
Alarm trigger size* | 0x74 | Less than or equal to event array size; Default: 18
Polling period* | 0x6F | 0x01 – 0x09 (1 – 30 sec) Default: 1 sec; see Table 2
LED* | 0x6C | 0x30 or 0x31 (Off or On) Default On

Table 1. Two-byte write commands. The five settings marked with an asterisk (*) are written to persistent storage; these data bytes are retained with power cycling.

The command descriptions are as follows:

- System reset restores the default settings. This can be sent with other commands, but they will be ignored.
- An alarm state is cleared with 0x61 0x30. Alarm can be set by master with 0x61 0x31; use for testing.
- Sending 0x70 0x30 turns the sensor off and reduces power consumption to minimum. Previously set monitoring parameters in Table 1 are retained. The sensor is re-activated with 0x70 0x31.
- Background size: The sensor must learn about the nominally quiet background, i.e. with no noise or leaks present. This data is used to automatically set the sensitivity level. The background acoustic level is acquired at 1 second intervals for the specified number of counts. Default background size is 30 counts = 30 seconds. A new training session is performed: i) at startup, ii) whenever the background count is set, eg. 0x62 0x1E, or iii) on system reset. The green-red LEDs blink in sequence whenever a training session is initiated.
- The event array size and alarm trigger size are configurable from 10 to a maximum of 255. These arrays record the number of events below and above the sensitivity level found in the training session. The oldest events are discarded from the arrays as each new event is added. An alarm condition exists when the sum of events above the sensitivity level (leak_count) reaches the alarm trigger size. Alarm trigger size must be less than or equal to event array size.

- Polling period determines the rate at which the sensor makes an acoustic measurement. The period is set with one of the data bytes in Table 2. Longer measurement intervals reduce battery power consumption. Default is 2 seconds.
0x01 | 0x02 | 0x03 | 0x04 | 0x05 | 0x06 | 0x07 | 0x08 | 0x09
1 sec | 2 sec | 3 sec | 5 sec | 10 sec | 15 sec | 20 sec | 25 sec | 30 sec

Table 2. Polling period data byte is set with command 0x6F

- The LED command (0x6C) disables (0x30) or enables (0x31) surface-mount LEDs on the PCB. Visual indicators can be useful for configuring and evaluating the device, but should be turned off after the sensor is deployed. Default is enabled (on).

Example command string: The 4-byte sequence 0x6F 0x03 0x6C 0x30 sets the monitor period at 3 seconds and turns the LEDs off.

Monitor parameters can be set while in the sleep state. The five parameters in Table 1 marked with an asterisk (*) are written to persistent storage and will be retained with power cycling.

2. Sensor status (read only) The sensor status can be obtained at any time by asserting START, sending the 7-bit slave address with the R/W bit set, and then reading the 12-byte sequence shown in Table 3. The master should follow the sequential read by asserting NACK then STOP.
Byte 0 | Byte 1 | Byte 2 | Byte 3 | Byte 4 | Byte 5
Alarm | Noise alert | quiet_count | leak_count | noise_count | background_size
Byte 6 | Byte 7 | Byte 8 | Byte 9 | Byte 10 | Byte 11
event_size | trigger_size | Period | LED | Sleep | Version

Table 3. 12-byte sensor status string.

- Byte 0 is set to 0x01 if an alarm exists; 0x00 otherwise. The digital output line marked ALARM is switched high when an alarm situation is detected. The host can monitor this line with an interrupt so it is not necessary to poll the status of Byte 0. The firmware can be configured to place the sensor into a sleep state when an alarm is detected or it can continue acquiring and processing data.
- Byte 1 is set when leak_count < trigger_size AND leak_count + noise_count ≥ trigger_size; 0x00 otherwise. This provides a warning that the sensor is operating in a noisy environment. The digital output line marked NOISE is also switched to high.
- Byte 2 is the current count (in hexadecimal) of below-sensitivity level quiet events.
- Byte 3 is the current count (in hexadecimal) of above-sensitivity level leak events.
- Byte 4 is the count (in hexadecimal) of noise events. The sensor ignores these events when assessing for the presence of a leak, which helps prevent false alarms.
- Bytes 5−8 are defined in Section V.1.

- Byte 9 indicates if the LEDs are off (0x00) or on (0x01).
- Byte 10 indicates if the sensor is sleeping (0x00) or active (0x01).
- Byte 11 is the firmware version running on the sensor.

Note: The status bytes are not accessed individually in designated registers as is often done with I2C slave devices. All 12 status bytes should be readout and parsed as required.

## VI. Modifying the Firmware

The AquaPing is an open-source hardware project licensed under Creative Commons. Inspection, experimentation, and modification of the installed firmware is encouraged. Development was done using Code Composer Studio 9.3.0 on an Ubuntu-Linux platform. CCS is a free download from Texas Instruments and provides an Eclipse-style interface. The MSP430FR59941 MCU on the PCB is flashed using the Spy-Bi-Wire two-terminal interface marked RESET and TEST on the leak sensor PCB. Almost any variety of inexpensive TI Launchpads can be used for this purpose. The Launchpads have a debugger and an Energy Trace function that is useful for identifying code inefficiencies and estimating battery life. Alternatively, compiled binaries can be flashed with the MSP430-BSL made by Olimex. The AquaPing code is thoroughly documented and available for download on the MicroPhonon github. (https://github.com/microphonon/acoustic-leak-detector/tree/main/firmware)

The Texas Instruments MSP DSP Library (https://software-dl.ti.com/msp430/msp430_public_sw/mcu/msp430/DSPLib/1_30_00_02/exports/html/index.html) must be installed on the development platform, also a free download. Use your file explorer to copy the dsplib directory directly into the CCS project folder. Enable DSP by navigating to:

CCS Build: MSP430 Compiler: Include Options

and adding the following line:

${PROJECT_ROOT}/dsplib/include

## VII. Troubleshooting

1. The red LED continues to blink three times. If the polarity is correct on the 3V3 and GND pins,
the green-red LEDs will blink in sequence to signal the start of training. If the red LED blinks three times at approximately 10 second intervals, then the ADC is in a state of constant overload. This is most likely due to a noisy 3V3 power source that is causing oscillation in the analog front end electronics. Try adding more filter capacitance or a capacitance multiplier circuit. The unfiltered 3V3 output supplied by USB experimenter boards is generally too noisy to operate the AquaPing. Battery power is ideal.

## 2. AquaPing won’t exit training mode – only get double-blinks from red LED. The training

session will attempt to acquire a set of stable background signals. At the end of the training time (30 seconds is default), either the green LED will flash once and the sensor will transition to monitoring or the red LED will flash twice indicating that the firmware is rejecting the training data. The training session will immediately repeat and loop indefinitely until it succeeds. If the device gets stuck in training mode, the user can try lengthening the training time by increasing the background sample size. An I2C configuration command is required (Section V). If this doesn’t work, there are two likely explanations: Either the 3V3 power line has excessive noise (see above) or the sensor is being deployed in an environment that is too noisy and/or unstable for reliable leak detection.
3. Leaks are indicated when none are present. If the LEDs are enabled, red will blink once after each
polling cycle when in monitor mode and a suspected leak signal is detected. If this happens continuously without known high-frequency acoustic signals being present, this means conditions have changed since the training session. The cause may be acoustic/electrical noise, inadequate grounding/shielding, or even the emergence of vibrations. Try re-training the device by pressing the manual reset button or issuing an appropriate I2C command (Section V).
4. No alarm is signaled when placed near an obvious leak. The design targets small leaks that
generally emit very weak acoustic signals. Bigger leaks are loud and erratic, which the AquaPing will interpret as noise (double blink from red LED). Dynamic range cannot be infinite, so a trade-off was made to detect weak signals while maintaining reasonably high reliability.
5. Audio from an entertainment center is interpreted as a leak. The sensor has been engineered to
ignore most background noises, especially on a long enough timescale, but it is not perfect. Some types of music or other sustained high-frequency audio sources may trigger false alarms. It is important that the user assess the suitability of the local environment before deploying the device.

### 6. LEDs can’t be turned off. LEDs are on by default. To reduce the component count and

manufacturing complexity, there is no switch or jumper on the PCB to disable the LEDs. LED control is implemented with an I2C command (Section V).

7. I2C communication doesn’t work. Check that the SDA and SCL lines are correctly wired and pullup resistors connected to 3V3 are present. The default slave address is 0x77; this can be changed with a firmware edit.
8. The white rectangular Helmholtz resonator has detached from the PCB. Glue it back on with
CA (super glue). Make sure there are no obstructions on either acoustic inlet hole (resonator or MEMS microphone). The resonator is not essential, but does provide sensitivity enhancement and some noise reduction.

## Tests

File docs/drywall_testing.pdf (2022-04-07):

## Acoustic detection of water leaks behind drywall

M.P. Hasselbeck, MicroPhonon

mph@microphonon.com

Acoustic leak detection will be compromised in situations where obstructions are present in the path between leak and sensor, eg. walls, floors, and ceilings. Sound attenuation by these barriers will obviously impact detection sensitivity. High-frequency acoustics are more severely attenuated when passing through construction materials such as drywall, brick, plaster, or plywood. This will impact stand-off detection – it is much harder to hear leaks when an obstruction is in the path.

These barriers are not acoustically opaque, however, as attenuation decreases with frequency. This suggests the possibility of a sensor with dynamic frequency response. Response can shift to lower frequencies depending on the ambient background noise, allowing for stand-off sensing with enhanced sensitivity as the situation allows, eg. in an unoccupied room. Such an adaptive design balances the fundamental trade-off between noise immunity and sensitivity.

A second approach uses a single sensor attached to the wall. Leaks can be detected behind a drywall barrier and over a wide area. The acoustic transducer does not need to penetrate the wall.

To assess and quantify these design concepts, a length of drywall was built, enclosing two wellcharacterized, simulated leak sources. The outdoor test structure is a 4 x 8 ft²
frame consisting of
6 internal sections defined by 2 x 4 in joists on the standard 16 in centers. The frame is enclosed by screwing on two 4 x 8 ft² pieces of water-repellent drywall, with the coated surfaces facing inside. External bracing is added along with two 0.04 gpm irrigation foggers at nominal utility water pressure, located inside the wall as shown in Figure 1 (left). The foggers simulate water leaks and can be independently activated.

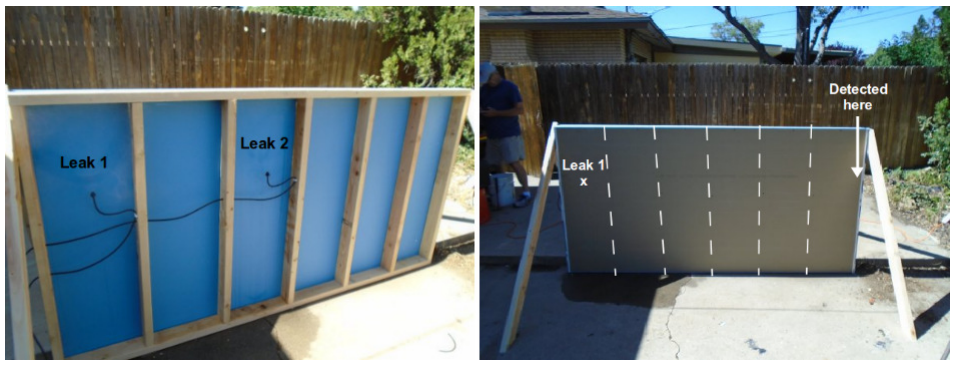
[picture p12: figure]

Figure 1: Test structure for evaluating internal wall leaks. Leaks are simulated with two 0.04 gpm irrigation foggers (left). Photo taken prior to front drywall panel being screwed onto the joists. The left-most leak is readily detected with an acoustic sensor placed outside the drywall at the far right of the structure (right). Dashed vertical lines indicate joist locations.

Absorption of acoustic energy as it passes through drywall depends on frequency; higher frequencies are more strongly attenuated. A sensor with an analog high-pass filter cutoff of 10 kHz reliably detects the leak signal at no more than 3 ft from the wall. This is an order of magnitude less than the free-space distance with no barrier present. Sensors with a lower cutoff of 8 kHz can detect at ∼ 9 ft. Reducing the cutoff to a lower frequency would likely push the detection distance of an interior wall leak further. There is, however, a trade-off between greater spectrum capture and unwanted noise pickup, which increases the probability of false triggers. This suggests an automated, dynamic filter scheme, in which the high-pass cutoff frequency shifts in response to the ambient noise background. The complete audio spectrum is available and can be used to advantage. Analysis of lower frequencies could identify human activity and the corresponding increased likelihood of false triggers. It is important to emphasize that no intelligible conversation is detected. The high-pass cutoff frequency and sensitivity can adjust accordingly. Reliable stand-off detection of interior wall leaks would then be possible when the ambient is sufficiently quiet, eg. in an unoccupied building or sleeping home. Adaptive or “smart” filtering could be implemented with a digital signal processor that analyzes the spectrum of the streaming audio.

The second design places the sensor directly on the test wall. A single leak is detected anywhere on the 8 ft span, despite the presence of up to 5 joists in the path. This is depicted in Figure 1 (right). Moving the sensor out of contact with the wall at the far-edge position shown in the figure causes the signal to disappear. The tentative explanation is that the wall is acting as an acoustic waveguide. An evanescent wave couples enough energy across the drywall boundary that it can be detected with excellent signal-to-noise. An estimate for the maximum potential detection range for contact wall sensing can be made by systematically decreasing detection sensitivity at a fixed position. Results of this experimentation predict that a span of drywall measuring 15 ft or more can be reliably monitored by a single wall-mounted sensor. It is important to emphasize that the device can be attached with simple adhesive or Velcro; a probe or microphone penetrating through the wall is not needed. A key advantage of this arrangement is that the microphone is monitoring in a direction directly opposite any room noise. An easily installed, small, lightweight sensor that monitors an entire wall for interior water leaks could be very attractive to the marketplace.

Key questions for proving the commercial feasibility of interior wall detection: What is the effect of wall insulation? How far can a leak signal propagate inside drywall and be detected? Can the waveguide effect be duplicated in other materials such as plywood, brick, or concrete? The spectrum of the leak signal depends on the nature of the orifice. How is detection affected by different types of cracks and holes that may occur in plumbing?

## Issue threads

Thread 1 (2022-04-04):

To-do list

microphonon, 2022-04-04:
Need to add libraries for custom KiCAD schematic components and footprints

microphonon, 2022-04-07:
KiCAD design files, custom footprints, gerbers uploaded

Closed 2022-04-07.

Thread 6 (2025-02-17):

minimum working example for home assistant

gon0, 2025-02-17:
Not an issue, but a tutorial-/starter- request:

Dear AquaPing creator,

I have 2 AquaPings laying around since crowdfunding. The main reason of not using them yet, is that I found implementing it into home assistant has some burdens for me.
Some of them are: the example uses custom GUI elements, custom I2C component, an easy step-by-step tutorial is missing.

2 years have passed since the update for the home assistant component was done.

Do you think you could provide an easy starting tutorial?

The non-plus ultra would be a flashable bin-file, e.g. for Tasmota.

ESPhome is also fine, but I would prefer that it is only code to be pasted, connection of AquaPing to ESP32 - and done. (No installing of custom components, etc.)

Maybe, this also helps in selling more units.

Best wishes,
gon

gon0, 2025-02-17:
Dear Mike,

thank you for your quick reply.

I am with you, a tutorial is available for sure. I had mixed experiences with ESPHome, since it happened quite some times, that updates broke the complete device.
My Tasmota devices are running for years, I could migrate from one Home Automation to another, and just needed to change the MQTT settings in Tasmota.

I wanted to raise awareness for this case. Since I would like to use the devices, I will look into it.

Best wishes,
gon

Closed 2025-02-17.

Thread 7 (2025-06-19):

2025 Updates

mikecarr, 2025-06-19:
I just bought this and am now wondering if it will be updated for 2025?

mikecarr, 2025-06-20:
The homeassistant stuff is outdated, I am trying to get this to work. This is what I have so far (attached)

but I am not see any data coming in. Also, custom:bar-card is no longer supported.

[my-ha.yaml.txt](https://github.com/user-attachments/files/20829773/my-ha.yaml.txt)

[esphome.yaml.txt](https://github.com/user-attachments/files/20829778/esphome.yaml.txt)

mikecarr, 2025-06-20:
Also custom components is deprecated

https://developers.esphome.io/blog/2025/02/19/about-the-removal-of-support-for-custom-components/

On Thu, Jun 19, 2025 at 8:16 PM MicroPhonon ***@***.***>
wrote:

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

microphonon, 2025-06-20:
OK was not aware that custom devices were no longer supported at ESPhome although the AquaPing is still listed on their site:
[https://devices.esphome.io/devices/AquaPing](
https://devices.esphome.io/devices/AquaPing)

I have thoroughly documented the device communication/configuration protocol here:
[https://github.com/microphonon/acoustic-leak-detector/blob/main/docs/user_manual.pdf](https://github.com/microphonon/acoustic-leak-detector/blob/main/docs/user_manual.pdf)

I hope that can get you started. I will try to get it going again with ESPhome in the next couple of weeks. The first iteration, especially the bar card, was quite a bit of work.

mikecarr, 2025-06-20:
Another question, I have seen various information... do the SDA and SDL pins need pull resistors? I've read they they are already on the board.

microphonon, 2025-06-20:
The AquaPing does not have pullup resistors on the I2C interface (see manual). I used 4.7k during development. The D1-mini WiFi module that I used with ESPhome, however, DOES have pullup resistors on both SDA and SCL.

microphonon, 2025-06-20:
Looks like you got it, very nice work!

I remember having to get help in the HA online forum to get those bar graphs working. A big obstacle was changing the scale when the event set size changed.

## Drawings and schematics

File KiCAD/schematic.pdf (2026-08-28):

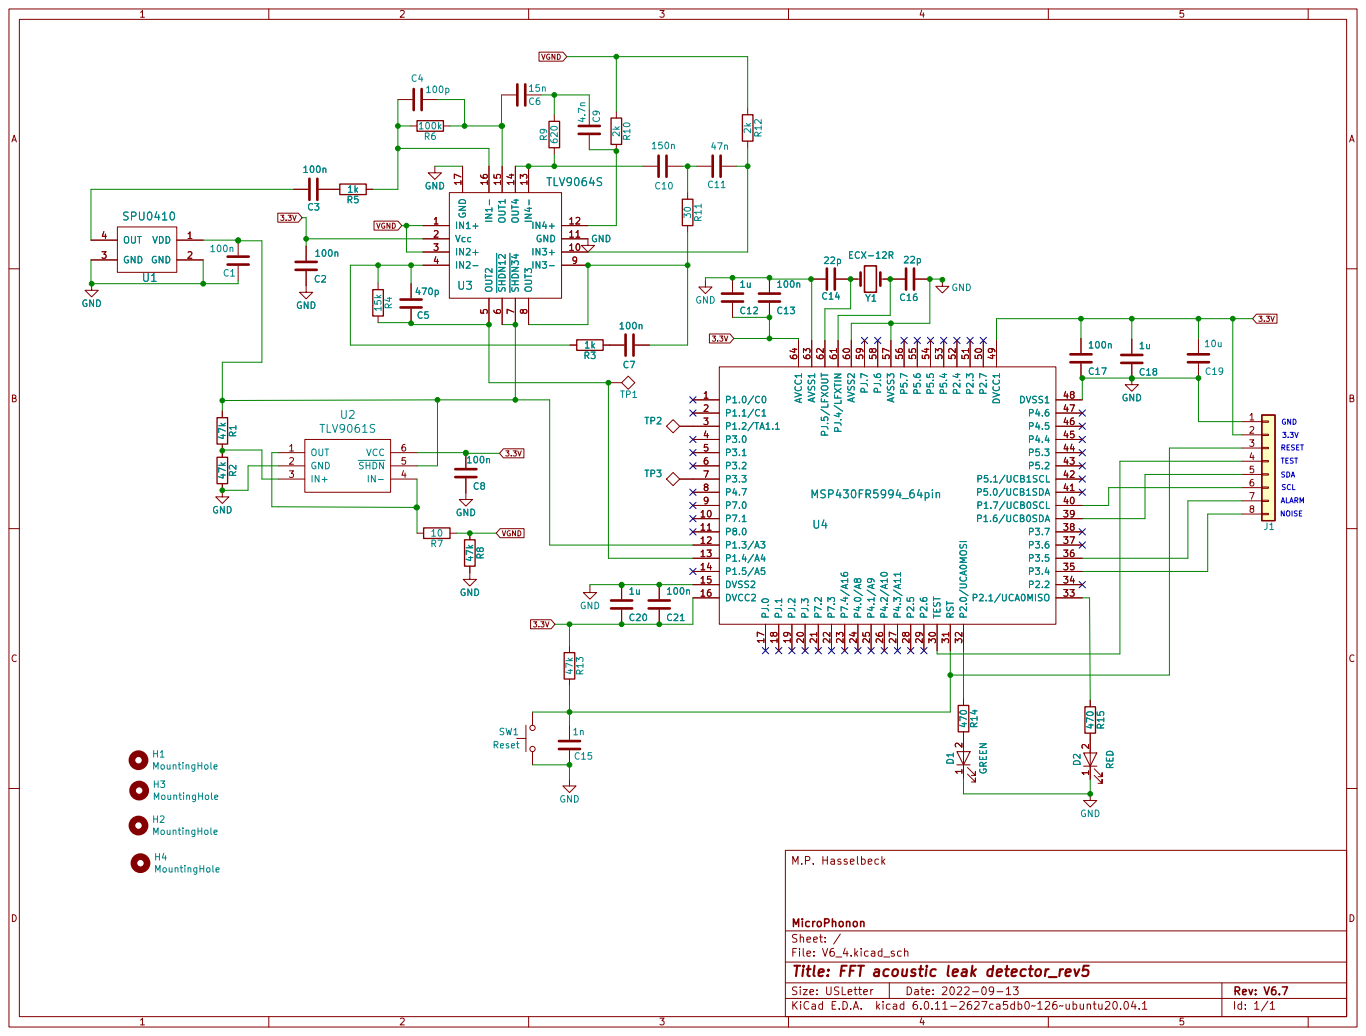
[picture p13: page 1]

35 P3.5
34 P3.4

Id: 1/1 Title: FFT acoustic leak detector_rev5

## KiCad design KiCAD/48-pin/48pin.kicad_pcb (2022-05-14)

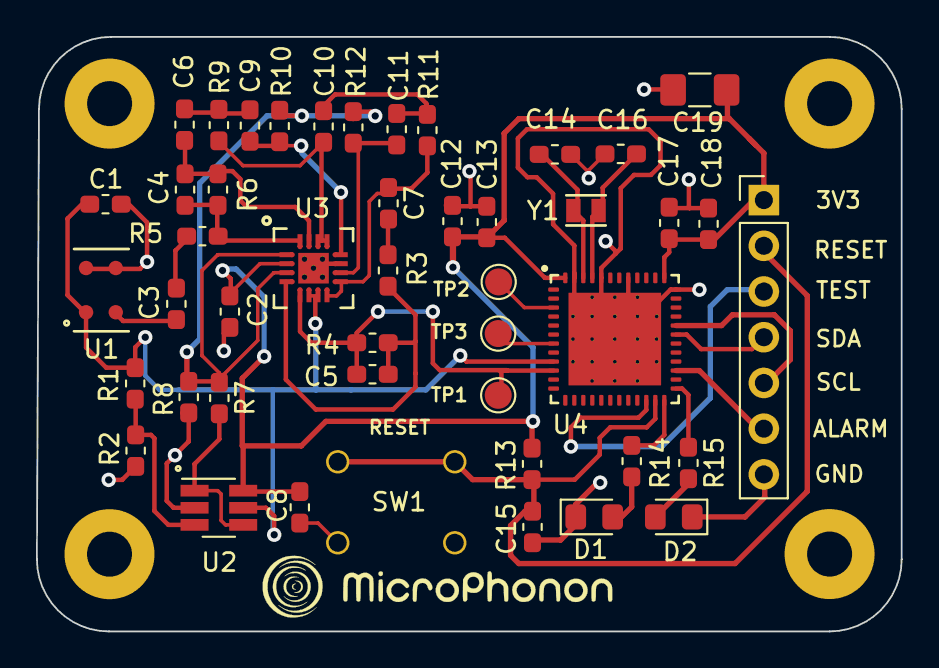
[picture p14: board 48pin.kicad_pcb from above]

Board: 2 copper layers, 48.0 x 33.0 mm, 50 parts (0 on the bottom side), 32 nets.

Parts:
C1, C2, C3, C7, C8, C13, C17: 100n; C_0603_1608Metric_Pad1.05x0.95mm_HandSolder
C4: 100p; C_0603_1608Metric_Pad1.05x0.95mm_HandSolder
C5: 470p; C_0603_1608Metric_Pad1.05x0.95mm_HandSolder
C6: 15n; C_0603_1608Metric_Pad1.05x0.95mm_HandSolder
C9: 4.7n; C_0603_1608Metric_Pad1.05x0.95mm_HandSolder
C10: 150n; C_0603_1608Metric_Pad1.05x0.95mm_HandSolder
C11: 47n; C_0603_1608Metric_Pad1.05x0.95mm_HandSolder
C12, C18: 1u; C_0603_1608Metric_Pad1.05x0.95mm_HandSolder
C14, C16: 22p; C_0603_1608Metric_Pad1.05x0.95mm_HandSolder
C15: 1n; C_0603_1608Metric_Pad1.05x0.95mm_HandSolder
C19: 10u; C_1206_3216Metric_Pad1.42x1.75mm_HandSolder
D1: GREEN; D_0805_2012Metric_Pad1.15x1.40mm_HandSolder
D2: RED; D_0805_2012Metric_Pad1.15x1.40mm_HandSolder
H1, H2, H3, H4: MountingHole; MountingHole_2.5mm_Pad
J1: I2C; PinHeader_1x07_P2.54mm_Vertical
R1, R2, R8, R13: 47k; R_0603_1608Metric_Pad1.05x0.95mm_HandSolder
R3, R5: 1k; R_0603_1608Metric_Pad1.05x0.95mm_HandSolder
R4: 15k; R_0603_1608Metric_Pad1.05x0.95mm_HandSolder
R6: 100k; R_0603_1608Metric_Pad1.05x0.95mm_HandSolder
R7: 10; R_0603_1608Metric_Pad1.05x0.95mm_HandSolder
R9: 620; R_0603_1608Metric_Pad1.05x0.95mm_HandSolder
R10, R12: 2k; R_0603_1608Metric_Pad1.05x0.95mm_HandSolder
R11: 30; R_0603_1608Metric_Pad1.05x0.95mm_HandSolder
R14, R15: 470; R_0603_1608Metric_Pad1.05x0.95mm_HandSolder
SW1: Reset; SKHHAMA010
TP1, TP2, TP3: TEST; TestPoint_Pad_D1.5mm
U1: SPU0410; SPU0410H
U2: TLV9061S; SOT-23-6_Handsoldering
U3: TLV9064S
U4: MSP430FR59941; MSP430FR5994IRGZ
Y1: EXC-12R; ECX-12R

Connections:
3.3V: C2.2, C8.1, C12.1, C13.1, C17.1, C18.1, C19.1, J1.1, R13.1, U2.6, U3.2, U4.37, U4.48
GND: C1.1, C2.1, C8.2, C12.2, C13.2, C14.2, C15.2, C16.1, C17.2, C18.2, C19.2, D1.1, D2.1, J1.7, R2.2, R8.2, SW1.1, U1.2, U1.3, U2.2, U3.11, U3.17, U4.36, U4.41, U4.44, U4.47, U4.49
unnamed: C1.2, R1.1, U1.1, U2.5, U3.6, U3.7, U4.9
unnamed: C3.1, R5.2
unnamed: C3.2, U1.4
unnamed: C4.1, C6.2, R6.1, U3.15
unnamed: C4.2, R5.1, R6.2, U3.16
unnamed: C5.1, R3.2, R4.1, U3.4
unnamed: C5.2, R4.2, TP1.1, U3.5, U4.10
unnamed: C6.1, C9.2, R9.2
unnamed: C7.1, R11.2, U3.8, U3.9
unnamed: C7.2, R3.1
unnamed: C9.1, R10.2, U3.12
unnamed: C10.1, C11.2, R11.1
unnamed: C10.2, R9.1, U3.13, U3.14
unnamed: C11.1, R12.2, U3.10
unnamed: C14.1, U4.46, Y1.1
unnamed: C15.1, J1.2, R13.2, SW1.2, U4.23
unnamed: C16.2, U4.45, Y1.2
unnamed: D1.2, R14.2
unnamed: D2.2, R15.2
unnamed: J1.3, U4.22
unnamed: J1.4, U4.31
unnamed: J1.5, U4.32
unnamed: J1.6, U4.27
unnamed: R1.2, R2.1, U2.3
unnamed: R7.2, U2.1, U2.4
unnamed: R14.1, U4.24
unnamed: R15.1, U4.25
unnamed: TP2.1, U4.3
unnamed: TP3.1, U4.7
VGND: R7.1, R8.1, R10.1, R12.1, U3.1, U3.3

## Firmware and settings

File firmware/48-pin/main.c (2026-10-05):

/* Firmware for the AquaPing acoustic leak detector running on a 48-pin MCU
   MSP430FR5994*. Developed with TI MSP-EXP430FR5994 Launchpad
   using Code Composer Studio v9.3 on Ubuntu-Linux.

   MCLK = SMCLK = 8 MHz sourced by DCO
   ACLK = 32768 Hz sourced by Timer_B0
   SMCLK sources Timer_A1 for ADC12

   Enable DSP by by placing the following line:
   ${PROJECT_ROOT}/dsplib/include
   in CCS Build: MSP430 Compiler: Include Options
   Must have the TI dsplib folder in project directory

     P1.0 NC
     P1.1 NC
     P1.2 Timer A1 output (TA1.1) TP2
     P1.3 Pulsed bias
     P1.4 A4 (ADC input) TP1
     P1.5 NC
     P1.6 UCB0 SDA
     P1.7 UCB0 SCL

     P2.0 Green LED
     P2.1 Red LED
     P2.2--2.7 NC

     P3.0 NC
     P3.1 NC
     P3.2 NC
     P3.3 Option to toggle this pin after each ADC12 conversion (TP3)
     P3.4 Leak alarm pin
     P3.5--3.7 NC

     P4.0--4.7 NC

     PJ.4 and PJ.5 connect to external 32.768 kHz crystal for LFXT

     Firmware version 52. Licensed under Creative Commons. MicroPhonon October 2026  */

#include <msp430.h>
#include <stdint.h>
#include <math.h>
#include <stdbool.h>
#include "DSPLib.h"

void SetTimer(void);
void SetClock(void);
void SetPins(void);
void SetI2C(void);
void SetADC(void);
void SetDMA(void);
void ReadCommands(void);
void ArrayUpdate(uint8_t state);
void Sleep(void);
void MeasureNoise(void);
uint32_t CheckMic(void);
uint16_t Rate(uint8_t rindx);
void SetParam(uint8_t p1, uint8_t p2);
void blink(uint8_t led_select);

//Un-comment the following line if sensor should go into sleep mode when alarm detected
//#define SLEEP
# define FIRMWARE 52
# define SLAVE_ADDRESS 0x77
# define MICSAMPLES 5  //Number of times microphone is polled for impulse noise rejection
# define SBYTES 12 //Number of status bytes
# define COMMAND_BYTES 8 //Number control commands
# define DATASET 20 //Default value for arraysize
# define TRIGGER 18 //Default value for alarmsize
//The following delays assume Timer B is 1.024 kHz (DCO/32)
# define IWAIT 40 // Time to wait before enabling ADC
# define NWAIT 10 //Time interval between multiple acquisitions
# define SAMPLING_PERIOD 239 //Counts for 8 MHz SMCLK; 240 gives 33.333 kHz
# define SAMPLE_TIME 200 //Set at 200 for ~5 us
# define ADC_SAMPLES 256
# define ADC_MAX 0x0FFF //Maximum of 12-bit ADC
# define SAT_POINTS 10 // Maximum allowable number of ADC_SAMPLES that reach saturation voltage
//Use frequency step 130.2 Hz for ADC_SAMPLES = 256 at 33.333 kHz
# define FFT_LOW 54 //130*54 = 7000 Hz
# define FFT_HIGH 88 //130*88 = 11.5 kHz
# define MEAN_MULT 2 //Multiplies the standard deviation to check for environmental noise
//Next 2 parameters help set background noise level
# define BACKGROUND_SAMPLES 30 //Default value 30 seconds; can be changed by user in range 10--255
# define NOISE_MULT 2 //Larger NOISE_MULT allows more fluctuation in ambient background
# define BLINK 100 //LED flash time
# define ALARM_ON P3OUT |= BIT4; //Alarm high on P3.4
# define ALARM_CLEAR P3OUT &= ~BIT4;
# define BIAS_ON P1OUT |= BIT3; //Pulsed bias on P1.3
# define BIAS_OFF P1OUT &= ~BIT3;

enum states {QUIET, NOISE, LEAK, IMPULSE};

struct  //Use a bit-field for binary flags
{
    uint8_t leak:1;
    uint8_t quiet:1;
    uint8_t noise:1;
    uint8_t background:1;
    uint8_t saturation:1;
} flag;

struct //These are the 3 counting arrays
{
    uint8_t trigger;
    uint8_t ok;
    uint8_t noise;
} counts[256];

uint32_t noise_array[256]; //Reserve array space for the background acquisition function
uint16_t sens_nv, bavg, bdev; //Global variables for ambient background
uint8_t Status_array[SBYTES], RxData[COMMAND_BYTES + COMMAND_BYTES], RxBuffer;
volatile uint8_t RxCount, *PRxData; //For master command data
uint16_t ADC_array[ADC_SAMPLES], *ADC;
// Analog input signal and FFT result
DSPLIB_DATA(input,MSP_ALIGN_FFT_Q15(ADC_SAMPLES))
_q15 input[ADC_SAMPLES];

/* Initial firmware settings. Any adjustment to these 5 settings by master
will persist on power off. These variables must be placed outside main program. */
#pragma PERSISTENT(arraysize)
uint8_t arraysize = DATASET;
#pragma PERSISTENT(alarmsize)
uint8_t alarmsize = TRIGGER;
#pragma PERSISTENT(poll_nv)
uint8_t poll_nv = 0x02; // Polling period: 1 sec (0x01) 30 sec (0x09)
#pragma PERSISTENT(bsamples)
uint8_t bsamples = BACKGROUND_SAMPLES;
#pragma PERSISTENT(led)
uint8_t led = 0x01; //On (0x01), off (0x00)

void main(void) {

    WDTCTL = WDTPW | WDTHOLD;   //Stop watchdog timer

    volatile uint8_t i, j;
    uint8_t sum_ok, sum_trigger, sum_noise, Size_check[COMMAND_BYTES];
    uint32_t sum4, var5, sdev, avg_sum4, sig_array[MICSAMPLES], *PSigs;
    int32_t diff;
    int64_t sum5;

     /* Status_array elements 5--9 are different from these default values
     when read from persistent storage. */
     Status_array[0] = 0x00; //Alarm status; 0x00 is OK
     Status_array[1] = 0x00; //Noise warning
     Status_array[2] = 0x00; //Below threshold events
     Status_array[3] = 0x00; //Above threshold events
     Status_array[4] = 0x00; //Noise events
     Status_array[5] = bsamples;
     Status_array[6] = arraysize;
     Status_array[7] = alarmsize;
     Status_array[8] = poll_nv; //Loop period selection byte
     // Status_array[8] = 0x01; //Always set loop period to 1 sec on startup
     Status_array[9] = led;
     Status_array[10] = 0x01; //Sensor is active
     Status_array[11] = FIRMWARE; //Firmware version

    //Initialize the three event counter arrays; will be working with array subset defined by arraysize
    for (i=0; i < arraysize; i++)
    {
        counts[i].trigger=0;
        counts[i].ok=0;
        counts[i].noise=0;
    }
    for (i=0; i < MICSAMPLES; i++)
    {
        sig_array[i]=0; //For averaging ADC acquisitions
    }
    for (i=0; i < COMMAND_BYTES; i++)
    {
        Size_check[i] = i+2; //Use this array to check for presence of command byte pairs
    }
    RxCount = 0;
    flag.background = 1; //Set to acquire the background

    SetPins();
    SetDMA();
    SetI2C();
    SetClock();
    SetTimer();
    SetADC();
    PMMCTL0_H |= PMMPW_H; //Unlock Vref registers for ADC use
     __enable_interrupt(); //Enable global interrupts.

    /* The following clear-reset sequences must be used to enable Channels 1 and 2
       of the DMA, which are used for I2C data transfer. */
    DMA1CTL &= ~DMAEN;
    DMA1CTL |= DMAEN;

    DMA2CTL &= ~DMAEN;
    DMA2CTL |= DMAEN;

    while(1)  //Top of main loop
    {
    /*  Check if new data received from master. Receive data asynchronous with slave loop,
        but slave parameters only updated at start (here). Must be 2,4,6...or 2*COMMAND_BYTES or else ignored.
        Update Status_array with any new bytes. Slave will send Status_array any time requested. */
        if(RxCount != 0)
        {
            for(i=0; i < COMMAND_BYTES; i++) //Check if any byte pairs arrived on I2C bus from master
            {
                if (RxCount == Size_check[i]) //Master can send commands in any order
                {
                      ReadCommands(); //Correct byte count found; read master command bytes
                }
            }
        }
       /* Check if background count was changed by master or there was a system startup/reset.
           Start training session by acquiring and analyzing the background level */
        if(flag.background == 1)
        {
         /* A green-red LED sequence signals start of background acquisition.
            Will remain in MeasureNoise() indefinitely until a stable acoustic
            environment exists. */
            blink(1);
            TB0CCR0 = BLINK;
            LPM3;
            blink(2);
            MeasureNoise();
            sens_nv = bavg + bdev;
            flag.background = 0; //Clear the flag
        }
        //Monitor mode starts here
         for (i=0; i < MICSAMPLES; i++) sig_array[i]=0; //Clear just in case
         TB0CCR0 = Rate(poll_nv); //Polling period for main loop with timer TB0
         LPM3;      //Wait in LPM3 for timeout or status query from master
         // Timeout at TB0.
         sig_array[0] = CheckMic(); // Check the microphone signal level
         if (sig_array[0] == 0) //Check for saturation of ADC and record as noise
         {
             ArrayUpdate(NOISE);
         }
         else if (sig_array[0] < sens_nv) //Nothing heard
         {
             ArrayUpdate(QUIET);
         }
         else
         /* Heard something exceeding sensitivity threshold but below ADC saturation.
            Do rapid succession of microphone measurements. */
             {
                 flag.saturation = 0;
                 for (i=1; i < MICSAMPLES; i++)
                 {
                     TB0CCR0=NWAIT; //Pause in LPM* between acquisitions
                     LPM3;
                     sig_array[i] = CheckMic();
                     if (sig_array[i]==0) //Check for ADC saturation
                     {
                         flag.saturation = 1;
                         break;
                     }
                 }
                 if (flag.saturation == 1) //Record as environmental noise
                 {
                     ArrayUpdate(NOISE);
                 }
                 else //No ADC saturation occurred so analyze the microphone data set
                 {
                     j=0;
                     sum4 = 0;
                     PSigs = sig_array; //Point to first element in sig_array
                     for (i=0; i < MICSAMPLES; ++i)
                     {
                         if (*PSigs > sens_nv) ++j;
                         sum4 += *PSigs++;
                     }
                     if (j == MICSAMPLES) //We have sustained signal. Check if this is from environmental noise
                     {
                         avg_sum4 = sum4/MICSAMPLES; //Average the integrated FFT signals
                         //Calculate standard deviation
                         sum5 = 0;
                         PSigs = sig_array;
                         for (i=0; i < MICSAMPLES; ++i)
                         {
                             diff = (*PSigs++) - avg_sum4;
                             sum5 += diff*diff;
                         }
                         var5 = sum5/(MICSAMPLES-1); //variance
                         sdev = sqrt(var5); //standard deviation
                   /* Compare standard deviation to signal average. Large standard deviation is signature of
                      environmental noise. Increasing MEAN_MULT allows for more fluctuation in FFT data. */
                         if(MEAN_MULT*sdev > avg_sum4) //Environmental noise detected
                         {
                             ArrayUpdate(NOISE);
                         }
                         else
                         {
                             ArrayUpdate(LEAK); //Record potential leak signal
                         }
                     }
                     else //Impulse noise detected; Not a leak signal, but count event as quiet
                     {
                         ArrayUpdate(IMPULSE); //IMPULSE is same as QUIET except flash green LED twice
                     }
                 }
             }
         /* Add new data to event count arrays. Arrays continuously updated; oldest data removed
            and newest data appended. Shift array indexes by 1. Remove oldest data first. */
              for (i=0; i < arraysize-1; i++)
                  {
                      counts[i].trigger=counts[i+1].trigger;
                      counts[i].ok=counts[i+1].ok;
                      counts[i].noise=counts[i+1].noise;
                  }
              //New data appended
              counts[arraysize-1].trigger = flag.leak;
              counts[arraysize-1].ok = flag.quiet;
              counts[arraysize-1].noise = flag.noise;
              //Sum the arrays with new data; the three counts will be placed in Status_array
              sum_ok = 0;
              sum_trigger = 0;
              sum_noise = 0;
              for (i=0; i < arraysize; i++)
              {
                  sum_trigger += counts[i].trigger;
                  sum_ok += counts[i].ok;
                  sum_noise += counts[i].noise;
              }
              //Count data placed in status array
              Status_array[2] = sum_ok;
              Status_array[3] = sum_trigger;
              Status_array[4] = sum_noise;
              //Check for the alarm condition
              #ifndef SLEEP
              {
                  if(sum_ok + sum_trigger + sum_noise >= alarmsize) //Don't clear alarm until enough data accumulated
                  {
                          if (sum_trigger >= alarmsize)
                          {
                              Status_array[0]=0x01; //Alarm flag
                              //Alarm identified; clear arrays so can start counting fresh
                              for (i=0; i < arraysize; i++)
                              {
                                  counts[i].trigger=0;
                                  counts[i].ok=0;
                                  counts[i].noise=0;
                              }
                          }
                          else Status_array[0] = 0x00; //No alarm
                  }
              }
              #else
                  {
                      if (sum_trigger < alarmsize) Status_array[0] = 0x00; //No alarm
                      else
                      {
                          Status_array[0]=0x01; //Alarm flag
                          //Alarm identified; clear arrays so can start counting fresh
                          for (i=0; i < arraysize; i++)
                          {
                              trigger_count[i]=0;
                              ok_count[i]=0;
                              noise_count[i]=0;
                          }
                      }
                  }
            #endif
                  //No alarm but check for sustained noise; include suspected leak signals
                  if(Status_array[0] == 0)
                  {
                      if (sum_trigger + sum_noise >= alarmsize) Status_array[1]=0x01; //Set noise warning byte
                      else Status_array[1]=0x00;
                  }

             #ifndef SLEEP
             {
                 if (Status_array[0] == 0x01)  ALARM_ON //Set alarm pin
                 else ALARM_CLEAR //Clear alarm pin
             }
            #else
             {
                 if (Status_array[0] == 0x01) //Set output alert pin and go to sleep
                 {
                     Status_array[10]=0x00; //Sleep status byte set
                     ALARM_ON //Set alarm pin
                     Sleep();
                 }
             }
            #endif
    } //End of main polling loop
}

    #pragma vector=TIMER0_B0_VECTOR
     __interrupt void Timer_B (void)
     {
         LPM3_EXIT;
     }

    #pragma vector = EUSCI_B0_VECTOR
    __interrupt void USCI_B0_ISR(void)
     {
        switch(__even_in_range(UCB0IV, USCI_I2C_UCBIT9IFG))
         {
         case USCI_NONE:         break;           // Vector 0: No interrupts
         case USCI_I2C_UCALIFG:  break;           // Vector 2: ALIFG
         case USCI_I2C_UCNACKIFG:break;         // Vector 4: NACKIFG
         case USCI_I2C_UCSTTIFG: break;         // Vector 6: STTIFG
         case USCI_I2C_UCSTPIFG:                // Vector 8: STPIFG; Also enable UCSTPIE
                             UCB0IFG &= ~UCSTPIFG;
                             DMA1CTL &= ~DMAEN;
                             DMA1CTL |= DMAEN;
                             break;
         case USCI_I2C_UCRXIFG3: break;          // Vector 10: RXIFG3
         case USCI_I2C_UCTXIFG3: break;          // Vector 14: TXIFG3
         case USCI_I2C_UCRXIFG2: break;          // Vector 16: RXIFG2
         case USCI_I2C_UCTXIFG2: break;          // Vector 18: TXIFG2
         case USCI_I2C_UCRXIFG1: break;          // Vector 20: RXIFG1
         case USCI_I2C_UCTXIFG1: break;          // Vector 22: TXIFG1
         case USCI_I2C_UCRXIFG0: break;          // Vector 24: RXIFG0
         case USCI_I2C_UCTXIFG0:  break;         // Vector 26: TXIFG0
         case USCI_I2C_UCBCNTIFG: break;         // Vector 28: BCNTIFG
         case USCI_I2C_UCCLTOIFG: break;         // Vector 30: clock low timeout. Try to reset I2C bus
         case USCI_I2C_UCBIT9IFG: break;         // Vector 32: 9th bit
         default: break;
   }
 }
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

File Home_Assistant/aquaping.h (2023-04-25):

/*  Example code to interface the AquaPing leak sensor with Home Assistant using an ESP8266 WiFi module.  Requires installation of the ESPHome and the File editor Add-ons to modify this sketch. An example .yaml file is included in this directory. Developed and tested with a Lolin D1-mini, but should adapt to other devices using the Arduino IDE and equivalent libraries. This file must be placed in the directory config/esphome/ and shown as an #include in the yaml file. The sensor status is polled by the D1-mini at a period set by 'update_interval' in milliseconds. The retrieved status bytes are parsed, formatted, and sent to the HA frontend over WiFi and the serial terminal. 

The D1-mini module provides a UART to USB interface to allow serial communication with a PC. Any serial terminal program (eg. puTTY) should work; be sure to set equivalent baud rates. Configuration characters can be sent from the terminal as user input. Characters are echoed to the terminal then formatted into command strings as a sequence of hex bytes that are sent to the AquaPing. Syntax is in the user guide. 

Two-way communication between the AquaPing and D1-mini is via I2C. Pullup resistors are present on the module. The D1-mini can supply 3V3 external power to the sensor. Make sure a large electrolytic filter capacitor is on this line.

Consult the read.me file for more information.
 
Licensed under Creative Commons. Author: MPH MicroPhonon April 2023 */

#include "esphome.h"
#include <Wire.h>
#define SDA_PIN 4 //This is pin D2 on D1-mini
#define SCL_PIN 5 //This is pin D1 on D1-mini
#define ALARM_PIN D4 //Connect D4 to ALARM on AquaPing
// The noise pin interrupt is not used in this sketch. It is set in the yaml file on pin D3
  
#define SBYTES 12 //Number of status bytes
#define ISTRING 24 //Max characters from terminal input
#define CSTRING 16 //Max characters sent to slave on I2C
   
    const long update_interval = 10000; //Period to update Home Assistant with sensor data (ms)
    const long min_interval = 0; //Delay to escape polling loop and notify the network when alarm occurs; should be 0
    const uint16_t I2C_SLAVE = 0x77; //AquaPing address on I2C
    const uint16_t baud_rate = 9600; //UART serial baud rate for terminal program
  
    int i, j, error_code, k=0, bsize=0;
    volatile uint8_t flag_high = 0; 
    volatile uint8_t flag_low = 0; 
    volatile uint8_t first_pass = 1; 
    static char Status_array[SBYTES];
    char input_string[ISTRING], carray[CSTRING], led_byte = 0x01;
    unsigned long currentMillis, trigger; 
   
/* Home Assistant will query the D1 mini with a period defined by 'update_interval'. This is independent and distinct from the rate that AquaPing monitors the acoustic environment (polling_period). The HA GUI displays the 3 running counts and other monitoring parameters. */
  class AquaPing : public PollingComponent {
    public:
    Sensor *quiet_count = new Sensor();
    Sensor *leak_count = new Sensor();
    Sensor *noise_count = new Sensor();
    Sensor *polling_period = new Sensor();
    Sensor *event_array_size = new Sensor();
    Sensor *trigger_threshold = new Sensor();
    Sensor *background_array_size = new Sensor();
    AquaPing() : PollingComponent(update_interval) {}  
    float get_setup_priority() const override { return esphome::setup_priority::BUS; } //Access I2C bus
    
    void setup() override {
        pinMode(LED_BUILTIN, OUTPUT);
        Serial.begin(baud_rate);  //Start serial UART for terminal output via USB
        Wire.begin(SDA_PIN, SCL_PIN); //Setup I2C bus
        //attachInterrupt(digitalPinToInterrupt(ALARM_PIN), alarm_handler, CHANGE);
        attachInterrupt(digitalPinToInterrupt(ALARM_PIN), alarm_low, FALLING);
        attachInterrupt(digitalPinToInterrupt(ALARM_PIN), alarm_high, RISING);
        for(i=0;i<SBYTES;i++)Status_array[i]=0; //Clear status array
    }
    
    unsigned long previousMillis = millis();
    
// Update Home Assistant using the following loop running at "update_interval" milliseconds.
void update() override {
  
    //Flush the serial port on first pass
    if(first_pass == 1)
    {
        while (Serial.available() > 0) Serial.read(); 
        first_pass = 0;
    }
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

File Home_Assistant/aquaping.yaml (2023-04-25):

esphome:
  name: esphome-web-959f0c
  friendly_name: ESPHome Web 959f0c
  libraries:
    - "Wire"
  includes:
    - aquaping.h

esp8266:
  board: d1_mini

# Enable logging
logger:

# Enable Home Assistant API
api:
  encryption:
    key: ""

ota:


wifi:
  ssid: !secret wifi_ssid
  password: !secret wifi_password

  # Enable fallback hotspot (captive portal) in case wifi connection fails
  ap:
    ssid: ""
    password: ""

captive_portal:

binary_sensor:
- platform: gpio
  pin: D3
  name: "AquaPing Noise Alert"
  id: noise
  icon: "mdi:volume-vibrate"
 
- platform: gpio
  pin: D4
  name: "AquaPing Leak Alert"
  id: leak
  icon: "mdi:water-pump"
  
# Not all of the retrieved data is displayed
sensor:
- platform: custom
  lambda: |-
    auto aquaping = new AquaPing();
    App.register_component(aquaping);
    return {aquaping->quiet_count,aquaping->leak_count,aquaping->noise_count,aquaping->polling_period,aquaping->event_array_size,aquaping->trigger_threshold,aquaping->background_array_size};

  sensors:
  - name: "Quiet Count Display" 
  - name: "Leak Count Display"
  - name: "Noise Count Display"
  - name: "Polling Period Display"  
  - name: "Event Size Display" 
  - name: "Trigger Threshold Display" 
  - name: "Background Set Size Display" 

number:
  - platform: template
    name: "Event array size"
    optimistic: true
    min_value: 10
    max_value: 255
    initial_value: 20
    step: 1
    mode: box
    id: event_input
    icon: "mdi:counter"

  - platform: template
    name: "Alarm trigger size"
    optimistic: true
    min_value: 10
    max_value: 255
    initial_value: 18
    step: 1
    mode: box
    id: trigger_input
    icon: "mdi:counter"

  - platform: template
    name: "Background array size"
    optimistic: true
    min_value: 10
    max_value: 255
    initial_value: 30
    step: 1
    mode: box
    id: background_input
    icon: "mdi:counter"

  - platform: template
    name: "Polling period"
    optimistic: true
    min_value: 1
    max_value: 9
    initial_value: 2
    step: 1
    mode: box
    id: polling_input
    icon: "mdi:timer-sand"
  
    
switch:
  - platform: template
    name: "LED Switch"
    restore_mode: ALWAYS_ON #8266 ignores this
    id: led
    icon: "mdi:led-outline"
    optimistic: true

  
  

    

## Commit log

2022-04-04 Create KiCAD
2022-04-08 Add files via upload
    AquaPing interfaced with a Lolin D1-mini WiFi module via I2C. The host PC can also send commands and receive data via a terminal program. This is done through the USB-UART interface on the D1-mini, w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
2022-04-10 Add files via upload
    Fixed bug that forced entry into sleep mode when LEDs instructed to turn off. Now firmware version 37
    [main.c]
2022-04-10 Add files via upload
    Fixed some small bugs.
    [D1_mini.ino]
2022-04-18 Add files via upload
    Populated board before adding thru-hole and resonator
2022-05-07 Firmware version 39.
    Don't clear counts when the LED state is toggled. There is no need to re-acquire a data set if the user decides to turn off the LEDs.
2022-05-14 Revised Gerber files
2022-08-08 Firmware version 46
    Better management of low-power. Keep timer TA1 off until it is needed
2022-08-10 Out-of-box demo video
    This short .mp4 shows the AquaPing in monitor mode powered by 2 x AAA batteries. LEDs blink in response to the acoustics. Details in the User Manual.
2022-08-24 Background acquisition signaled by LEDs
2022-10-26 Version 47
    Minor edit to reset digital alert pins at the start of a training session
    [main.c]
2022-11-05 Ver 48 minor bug fix
    [main.c]
2022-11-22 Fixed a couple of typos is user manual
2023-01-11 Firmware version 49
    Alternate version of the code that uses more efficient ring buffers for the counting arrays. Saves CPU cycles but may not have noticeable effect on battery life?
2023-06-04 Update readme.md
    Link to new page that describes how to interface a custom I2C sensor to the Home Assistant dashboard.
2026-08-28 Add files via upload
    AquaPing KiCad schematic
2026-09-16 Firmware version 50 update
    Syntiant acquired the Knowles product line of SiSonic MEMS microphones. In their new data sheet, Syntiant recommends a 40 ms delay after the application of bias voltage to allow the microphone to att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
2026-09-17 Update user manual
    Add a chart to the user manual that summarizes signaling from red and green LEDs on the PCB
2026-10-05 Minor firmware update
    Update resulting from a firmware review by claude.ai. The AI suggested increasing the memory allocated to some of the integer variables that are generated via arithmetic multiplication. This will reduce the risk of overflow and may increase the sensor dynamic range. Also fixed a small bug that writes Byte 10 of the Status_Array.
    [main.c]
2026-10-26 Update README.md
    Add a wiring diagram
2026-10-26 Add files via upload
    Add a conceptual wiring diagram to instructions
2026-10-26 Update README.md
    Add text for the i2cdriver hardware
2026-10-26 Update README.md
    Add text for an i2cdriver GUI
2026-10-30 Add files via upload
    Edit instructions to include info about using micropython with the RP Pico.
2026-11-03 Fix LED checkbox
    When the GUI starts up and makes a first read of the AquaPing status bytes, it checks if the LEDs have been disabled. If yes, the checkmark adjacent to `Enable LEDs` in the Control Panel is removed. This fixes a bug where the box is always in its default ON state at startup.
2026-11-12 Delete GUIs/arduino_terminal.ino
    Remove clutter
